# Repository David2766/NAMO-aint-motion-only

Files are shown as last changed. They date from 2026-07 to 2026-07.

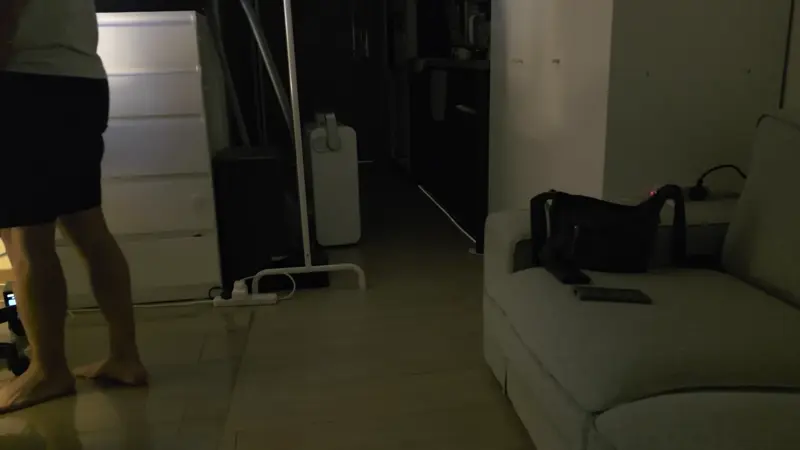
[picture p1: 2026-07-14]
docs/img/0_1.webp

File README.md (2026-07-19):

# NAMO

**NAMO Ain't Motion-Only.**<br>
*Still here, even when you're still.*

A fully local mmWave spatial presence platform with live floorplan tracking, visual zones, and Home Assistant integration.

NAMO zone-based lighting automation demo
*As I move between detection zones, NAMO automatically switches the corresponding room lights using fully local presence detection.*

## English

NAMO is a fully local mmWave spatial presence platform with live floorplan tracking, visual zones, and Home Assistant integration.

It provides open-source ESPHome firmware for an XIAO ESP32S3 and LD2450-based presence sensor, external components, and a web dashboard embedded directly into the ESP32 firmware.

### What's Included

- ESPHome firmware entry file: `namo.yaml`
- Shared ESPHome package: `packages/namo/`
- ESPHome external component: `components/radar_api_server/`
- Embedded web dashboard source: `dashboard/`
- Release binaries: `release-assets/`

### Demo

A browser-only demo is available so you can try the embedded dashboard UI without an ESP32 device.

- Dashboard demo: https://david2766.github.io/NAMO-aint-motion-only/
- Initial Wi-Fi setup demo: https://david2766.github.io/NAMO-aint-motion-only/?setup=1

The demo uses mock data. It does not change real device settings, save Wi-Fi credentials, or perform firmware updates.

To run the dashboard locally:

```powershell
cd dashboard
npm ci
npm run dev:web
```

Then open one of the following URLs:

```text
http://localhost:5173/dashboard/?demo=1
http://localhost:5173/dashboard/?setup=1
```

### Project Status

<!-- release-firmware-version -->
NAMO v0.5.5 is currently a public beta.

PIR and confirmed LD2450 tracking can start a presence session, while the LD2450 also provides target position, room, zone, and exit evidence. New hardware can attach an optional LD2410C to maintain an already established session when the LD2450 loses a motionless person. The LD2410C cannot start presence by itself or create motion and spatial tracking results. NAMO is designed to retain presence more reliably than motion-only sensors, but perfectly motionless presence detection is not guaranteed in every room or installation. Detection performance depends on placement, range, orientation, and the surrounding environment.

LD2410C assistance arms only after its detection overlaps PIR or confirmed LD2450 presence for 2 seconds. Confirmed exit evidence or filter blocking vetoes the assistance. If stable presence ends without either veto, an armed LD2410C may reassert the same session for up to 30 seconds. Its detection distance is stabilized with a three-sample median for held-target display. Missing or unavailable LD2410C hardware is ignored, leaving the existing PIR and LD2450 behavior unchanged.

### Quick Start

Most users should use the prebuilt release binaries instead of building the firmware manually.

1. Download the firmware files from `release-assets/v<version>/` or from GitHub Releases.
2. For the first installation, follow the USB flashing instructions below and install the `factory` image.
3. For updating an already installed device, use the `ota` image.
4. After boot, connect to the device setup AP.
5. Open `http://192.168.4.1/setup` in a browser.
6. Select your Wi-Fi network and enter the password.
7. Copy the ESPHome API key shown on the setup screen.
8. After setup is complete, choose your integration mode from the dashboard.

The setup AP password is:

```text
psensor7777
```

The setup AP is a temporary network used only for initial provisioning. After Wi-Fi setup is complete, the device runs on your home Wi-Fi network.

### First USB Flash

1. Download `namo-v<version>-factory.bin` from GitHub Releases.
2. Connect the XIAO ESP32S3 to your computer with a data-capable USB cable.
3. Open [ESPHome Web](https://web.esphome.io/) in Chrome or Edge.
4. Click **Connect** and select the XIAO serial port.
5. Click **Install** and select the downloaded `factory` binary.
6. Wait for installation and reboot to complete.
7. Connect to the device setup AP and continue at `http://192.168.4.1/setup`.

Use the `ota` binary only for updates from the installed device's web dashboard. Do not use the `factory` binary for OTA updates.

### Hardware

NAMO requires a Seeed Studio XIAO ESP32S3 with 8MB Flash / 8MB PSRAM and an LD2450-series radar. The LD2410C presence-assist radar, PIR, light, and environmental sensors are optional.

See the [hardware guide](hardware/README.md) for the complete parts list, pinout, wiring notes, PCB manufacturing files, enclosure models, and DIY build instructions.

The current dual-radar Gerber files and schematic are published. The matching dual-radar enclosure is still being refined; the enclosure files currently available in the repository are for the earlier single-radar build.

### Device Name

The firmware uses ESPHome's `name_add_mac_suffix`.

This prevents name conflicts when flashing the same firmware to multiple devices. Devices will be registered with names similar to:

```text
presence-sensor-aabbcc
Presence Sensor AABBCC
```

The last six characters are generated from the last three bytes of the ESP32 Wi-Fi MAC address.

### Initial Setup

This firmware does not ship with a preconfigured Wi-Fi SSID or password.

Initial setup is done through the embedded `/setup` page. The user selects a Wi-Fi network and enters the password, then the device connects to that network and becomes available through the web dashboard.

The ESPHome API encryption key is generated automatically during the initial Wi-Fi setup flow. Copy the key shown on the screen and use it when adding the device to Home Assistant.

If you only use the SmartThings Edge Driver, you still need to complete the initial setup handoff once. The dashboard will ask you to choose the intended integration mode.

### Build

To build the firmware manually, validate and compile the ESPHome configuration from the repository root:

```powershell
esphome config namo.yaml
esphome compile namo.yaml
```

To generate the embedded web dashboard asset first:

```powershell
cd dashboard
npm install
npm run build:dashboard
```

The dashboard build generates:

```text
components/radar_api_server/dashboard_assets.h
```

To run dashboard tests from a downloaded source archive:

```powershell
cd dashboard
npm test
```

The normal `npm test` command runs setup-page i18n checks, replay parser tests,
and dashboard tests. Native PresenceTracker tests are separate because they
require `cl`, `g++`, or `clang++`; run `npm run test:native` explicitly. That
command fails with a clear message when no supported host compiler is available.

### Release Files

Release binaries are included under:

```text
release-assets/v<firmware-version>/
```

The files are split by purpose:

- `factory`: use this for the first USB flash
- `ota`: use this for updating an already installed device from the web dashboard

Use `checksums.txt` to verify downloaded file integrity.

### Web Dashboard

After flashing the device, open the dashboard in a browser:

```text
http://<device-ip>/dashboard
```

Main dashboard features:

- Real-time presence and motion status
- Radar target map
- Floorplan setup and editing
- Detection zones and false-positive correction zones
- Backup and restore
- Firmware update UI
- System information
- Home Assistant / SmartThings Edge mode selection
- Statistics and heatmap views

### Core Workflow

#### 1. Dashboard

View real-time presence, motion, and target status together with room-level presence and system information in one place.

When an LD2410C is available, the dashboard also shows whether the auxiliary presence sensor currently detects a target.

NAMO dashboard

#### 2. Radar Map

Track the position and movement of up to three LD2450 targets in real time using the radar's own coordinate system.

From the Zone Settings radar map, an available LD2410C can be tuned by distance band. Per-gate engineering telemetry is enabled only while the tuning panel is open and is disabled again when the panel closes.

NAMO radar map

#### 3. Floorplan Onboarding

Upload a floorplan, set its physical size and scale, analyze wall and room candidates, and place the radar through a guided workflow.

NAMO floorplan onboarding

#### 4. Room Editing

Refine automatically detected rooms with vertex editing, split and merge operations, or manually created room boundaries.

NAMO room editing

#### 5. Radar Position & Zone Editing

Match the radar's position and rotation to the floorplan, then edit detection, exclusion, correction, and exit areas while viewing the actual room layout.

NAMO radar position and zone editing

#### 6. Furniture Layout

Select a room, add furniture, and move, rotate, or resize each object so the floorplan reflects the real space more closely.

NAMO furniture layout

### Security Notes

Each device should use its own ESPHome API encryption key.

During initial setup, this firmware detects the default demo key, generates a new API key, and shows it to the user for copying.

Do not publish firmware images built with your personal settings. Before sharing a ROM file, make sure it does not contain your real Wi-Fi credentials or private API key.

The embedded dashboard is designed for local-network use. Avoid exposing the device directly to the public internet.

### Documentation

- [Documentation index](docs/README.md)
- [HTTP API contract](docs/api-contract.md)
- [Multi-sensor API design](docs/multi-sensor-contract.md)
- [Exit evidence](docs/presence-exit-zone.md)
- [Presence tracker](docs/presence-tracker.md)
- [Future tracker work](docs/presence-tracker-future.md)
- [Replay and validation plan](docs/presence-replay.md)
- [Presence simulation plan](docs/presence-simulation.md)

### Related Repositories

This project works together with the following repositories:

- NAMO firmware / embedded web dashboard: https://github.com/David2766/NAMO-aint-motion-only
- Home Assistant custom card: https://github.com/David2766/radar-zone-card-for-LD2450
- SmartThings Edge Driver: https://github.com/David2766/presence-sensor-smartthings-edge

### License

Copyright (c) 2026 David2766 and contributors.

The software and firmware are licensed under AGPL-3.0-or-later.

The hardware design and manufacturing files under [`hardware/`](hardware/) are licensed separately under [CC BY-NC-SA 4.0](hardware/LICENSE).

Third-party components retain their respective licenses. See [Third-Party Notices](THIRD_PARTY_NOTICES.md) and [Third-Party License Texts](THIRD_PARTY_LICENSES.txt).

### Notes

This project was planned and tested by the author, with OpenAI Codex used for code generation and refactoring throughout development.

---

## 한국어

NAMO는 실시간 평면도 추적, 시각적 감지 구역과 Home Assistant 연동을 제공하는 완전 로컬 방식의 mmWave 공간 재실 플랫폼입니다.

이 저장소에는 XIAO ESP32S3와 LD2450 기반 재실 센서용 오픈소스 ESPHome 펌웨어, 외부 컴포넌트, 그리고 ESP32 펌웨어에 직접 내장되는 웹 대시보드 소스가 포함되어 있습니다.

### 포함된 것

- ESPHome 펌웨어 진입 파일: `namo.yaml`
- ESPHome 공통 패키지: `packages/namo/`
- ESPHome 외부 컴포넌트: `components/radar_api_server/`
- 내장 웹 대시보드 소스: `dashboard/`
- 릴리즈 바이너리: `release-assets/`

### 데모 웹 페이지

실제 ESP32 기기 없이 내장 웹 대시보드 화면을 확인할 수 있는 데모 페이지를 제공합니다.

- 데모 주소: https://david2766.github.io/NAMO-aint-motion-only/
- 초기 Wi-Fi 설정 화면 데모: https://david2766.github.io/NAMO-aint-motion-only/?setup=1

데모에서는 데모 데이터를 사용하며 실제 기기 설정, Wi-Fi 저장, 펌웨어 업데이트는 수행하지 않습니다.

로컬에서 확인하려면 아래 명령을 사용합니다.

```powershell
cd dashboard
npm ci
npm run dev:web
```

그 다음 브라우저에서 아래 주소로 접속합니다.

```text
http://localhost:5173/dashboard/?demo=1
http://localhost:5173/dashboard/?setup=1
```

### 프로젝트 상태

<!-- release-firmware-version -->
NAMO v0.5.5는 현재 공개 베타 단계입니다.

PIR과 확정된 LD2450 트랙은 재실 세션을 시작할 수 있으며, LD2450은 타깃 위치, 방, 구역 및 퇴실 근거도 제공합니다. 신규 하드웨어에서는 선택 사항인 LD2410C가 LD2450이 움직이지 않는 사람을 놓쳤을 때 이미 시작된 재실을 유지할 수 있습니다. LD2410C 단독으로 재실을 새로 켜거나 움직임 및 공간 추적 결과를 만들지는 않습니다. NAMO는 움직임만 감지하는 센서보다 재실 상태를 안정적으로 유지하도록 설계되었지만, 모든 방과 설치 환경에서 완전히 움직이지 않는 사람의 감지를 보장하지는 않습니다. 감지 성능은 센서 배치, 거리, 방향 및 주변 환경의 영향을 받습니다.

LD2410C 보조는 PIR 또는 확정된 LD2450 재실과 2초 동안 함께 감지된 뒤에만 준비됩니다. 확인된 퇴실 근거나 필터 차단이 있으면 보조를 사용하지 않습니다. 두 차단 근거 없이 안정화 재실이 종료되면 준비된 LD2410C가 최대 30초 동안 같은 재실 세션을 다시 이어갈 수 있습니다. 보존 타깃 표시에 사용하는 감지 거리는 3개 표본의 중앙값으로 안정화합니다. LD2410C가 없거나 통신할 수 없으면 조용히 무시하고 기존 PIR 및 LD2450 동작을 그대로 유지합니다.

### 빠른 시작

일반 사용자는 직접 빌드하지 않고 릴리즈 바이너리를 사용하는 것을 권장합니다.

1. `release-assets/v<version>/` 또는 GitHub Releases에서 펌웨어 파일을 받습니다.
2. 처음 설치할 때는 아래 USB 플래싱 절차에 따라 `factory` 이미지를 설치합니다.
3. 이미 설치된 기기를 업데이트할 때는 `ota` 이미지를 사용합니다.
4. 부팅 후 기기의 설정 AP에 접속합니다.
5. 브라우저에서 `http://192.168.4.1/setup`으로 접속합니다.
6. 사용할 Wi-Fi를 선택하고 비밀번호를 입력합니다.
7. 화면에 표시되는 ESPHome API 키를 복사합니다.
8. 설정 완료 후 대시보드에서 사용 환경을 선택합니다.

설정 AP 비밀번호는 아래와 같습니다.

```text
psensor7777
```

설정 AP는 초기 설정을 위한 임시 네트워크입니다. Wi-Fi 설정이 완료되면 기기는 집 Wi-Fi로 동작합니다.

### 최초 USB 플래싱

1. GitHub Releases에서 `namo-v<version>-factory.bin`을 받습니다.
2. 데이터 전송이 가능한 USB 케이블로 XIAO ESP32S3를 컴퓨터에 연결합니다.
3. Chrome 또는 Edge에서 [ESPHome Web](https://web.esphome.io/)을 엽니다.
4. **Connect**를 누르고 XIAO의 시리얼 포트를 선택합니다.
5. **Install**을 누르고 다운로드한 `factory` 바이너리를 선택합니다.
6. 설치와 재부팅이 끝날 때까지 기다립니다.
7. 기기의 설정 AP에 연결한 뒤 `http://192.168.4.1/setup`에서 설정을 계속합니다.

`ota` 바이너리는 설치된 기기의 웹 대시보드에서 업데이트할 때만 사용합니다. OTA 업데이트에 `factory` 바이너리를 사용하지 마세요.

### 하드웨어

NAMO에는 8MB Flash / 8MB PSRAM 사양의 Seeed Studio XIAO ESP32S3와 LD2450 계열 레이더가 필요합니다. LD2410C 재실 보조 레이더, PIR, 조도 및 온습도 센서는 선택 사항입니다.

전체 부품 목록, 핀맵, 배선 주의사항, PCB 제작 파일, 케이스 모델 및 자작 안내는 [하드웨어 가이드](hardware/README.ko.md)를 참고하세요.

현재 듀얼 레이더 Gerber 파일과 회로도는 공개되어 있습니다. 듀얼 레이더용 케이스는 계속 다듬는 중이며, 저장소에 현재 공개된 케이스 파일은 구형 단일 레이더 구성용입니다.

### 기기 이름

ESPHome의 `name_add_mac_suffix`를 사용합니다.

따라서 같은 펌웨어를 여러 기기에 넣어도 이름 충돌이 나지 않습니다. 기기는 대략 아래와 같은 이름으로 등록됩니다.

```text
presence-sensor-aabbcc
Presence Sensor AABBCC
```

뒤의 6자리는 ESP32 Wi-Fi MAC 주소의 마지막 3바이트를 기준으로 생성됩니다.

### 초기 설정

이 펌웨어는 Wi-Fi SSID와 비밀번호를 펌웨어에 미리 넣지 않습니다.

초기 설정은 기기 안에 내장된 `/setup` 화면에서 진행합니다. 사용자가 Wi-Fi를 선택하고 비밀번호를 입력하면 기기가 해당 네트워크에 연결되고, 이후 웹 대시보드에서 사용할 수 있습니다.

ESPHome API 보안 키는 초기 Wi-Fi 설정 과정에서 자동으로 생성됩니다. 화면에 표시되는 키를 복사해 두었다가 Home Assistant에 기기를 추가할 때 사용합니다.

SmartThings Edge Driver만 사용하는 경우에도 초기 설정 마무리 과정은 한 번 진행해야 합니다. 대시보드에서 사용 환경을 선택하면 됩니다.

### 빌드

직접 빌드하려면 저장소 루트에서 ESPHome으로 설정을 확인하고 빌드합니다.

```powershell
esphome config namo.yaml
esphome compile namo.yaml
```

내장 웹 대시보드 asset을 먼저 생성하려면 아래 명령을 실행합니다.

```powershell
cd dashboard
npm install
npm run build:dashboard
```

대시보드 빌드는 아래 파일을 생성합니다.

```text
components/radar_api_server/dashboard_assets.h
```

다운로드한 소스 압축 파일에서 대시보드 테스트를 실행하려면 다음 명령을 사용합니다.

```powershell
cd dashboard
npm test
```

일반 `npm test`는 setup page i18n 검사, 리플레이 파서 테스트와 대시보드 테스트를
실행합니다. 네이티브 PresenceTracker 테스트는 `cl`, `g++`, `clang++` 중 하나가
필요하므로 `npm run test:native`로 별도 실행합니다. 지원하는 호스트 컴파일러가
없으면 이 명령은 원인을 명확히 표시하고 실패합니다.

### 릴리즈 파일

릴리즈용 바이너리는 아래 폴더에 포함됩니다.

```text
release-assets/v<firmware-version>/
```

파일 이름은 용도에 따라 나뉩니다.

- `factory`: 처음 USB로 플래시할 때 사용
- `ota`: 이미 설치된 기기를 웹 대시보드에서 업데이트할 때 사용

`checksums.txt`로 다운로드한 파일의 무결성을 확인할 수 있습니다.

### 웹 대시보드

기기 플래싱 후 브라우저에서 아래 주소로 접속합니다.

```text
http://<device-ip>/dashboard
```

웹 대시보드에서 제공하는 주요 기능은 다음과 같습니다.

- 실시간 재실 / 움직임 상태 확인
- 레이더 타깃 맵
- 평면도 설정 및 편집
- 감지 구역 / 오탐 보정 구역 설정
- 백업 및 복원
- 펌웨어 업데이트 UI
- 시스템 정보 확인
- Home Assistant / SmartThings Edge 사용 모드 선택
- 통계 및 히트맵 보기

### 핵심 사용 흐름

#### 1. 대시보드

실시간 재실·움직임·타깃 상태와 방별 재실 상태 및 시스템 정보를 한 화면에서 확인합니다.

LD2410C가 연결되어 있으면 보조 재실 센서가 현재 타깃을 감지하는지도 함께 표시합니다.

NAMO 대시보드

#### 2. 레이더맵

최대 3개 LD2450 타깃의 위치와 움직임을 레이더 좌표계에서 실시간으로 확인합니다.

구역 설정의 레이더맵에서는 연결된 LD2410C의 거리 띠별 민감도를 조절할 수 있습니다. 게이트별 engineering 계측은 튜닝 패널을 연 동안에만 활성화되고 패널을 닫으면 다시 비활성화됩니다.

NAMO 레이더맵

#### 3. 평면도 온보딩

평면도를 업로드하고 실제 크기와 축척을 설정한 뒤, 벽과 방 후보 분석 및 레이더 초기 배치를 단계별로 진행합니다.

NAMO 평면도 온보딩

#### 4. 방 편집

자동 인식된 방을 꼭짓점 편집, 분할, 병합으로 다듬거나 방 경계를 직접 생성할 수 있습니다.

NAMO 방 편집

#### 5. 레이더 위치 및 구역 편집

평면도 위에서 레이더 위치와 회전을 맞추고, 실제 공간을 보면서 감지 구역, 제외·오탐 보정 구역 및 퇴실 지점을 편집합니다.

NAMO 레이더 위치 및 구역 편집

#### 6. 가구 배치

방을 선택해 가구를 추가하고 이동, 회전, 크기 조절을 통해 평면도를 실제 공간과 비슷하게 구성합니다.

NAMO 가구 배치

### 보안 주의

ESPHome API 보안 키는 기기마다 고유하게 사용하는 것을 권장합니다.

이 펌웨어는 초기 설정 과정에서 기본 데모 키를 감지하면 새 API 키를 자동 생성하고, 사용자가 복사할 수 있도록 안내합니다.

개인 설정을 넣어 직접 빌드한 펌웨어 이미지를 공개하지 마세요. ROM 파일을 공유하고 싶다면 실제 사용 중인 Wi-Fi 정보나 개인 API 키가 포함되지 않았는지 확인해야 합니다.

내장 대시보드는 로컬 네트워크 사용을 전제로 합니다. 기기를 인터넷에 직접 노출하지 않는 것을 권장합니다.

### 관련 문서

- [문서 인덱스](docs/README.ko.md)
- [HTTP API 계약](docs/api-contract.ko.md)
- [다중 센서 API 설계](docs/multi-sensor-contract.ko.md)
- [퇴실 근거](docs/presence-exit-zone.ko.md)
- [재실 트래커](docs/presence-tracker.ko.md)
- [향후 트래커 작업](docs/presence-tracker-future.ko.md)
- [리플레이 및 검증 계획](docs/presence-replay.ko.md)
- [재실 시뮬레이션 계획](docs/presence-simulation.ko.md)

### 관련 저장소

이 프로젝트는 아래 저장소들과 함께 동작합니다.

- NAMO 펌웨어 / 내장 웹 대시보드: https://github.com/David2766/NAMO-aint-motion-only
- Home Assistant 커스텀 카드: https://github.com/David2766/radar-zone-card-for-LD2450
- SmartThings Edge Driver: https://github.com/David2766/presence-sensor-smartthings-edge

### 라이선스

Copyright (c) 2026 David2766 and contributors.

소프트웨어와 펌웨어는 AGPL-3.0-or-later 라이선스로 배포됩니다.

[`hardware/`](hardware/) 아래의 하드웨어 설계 및 제작 파일은 별도의 [CC BY-NC-SA 4.0](hardware/LICENSE) 라이선스로 배포됩니다.

제3자 구성요소에는 각 구성요소의 라이선스가 적용됩니다. 자세한 내용은 [제3자 고지](THIRD_PARTY_NOTICES.md)와 [제3자 라이선스 전문](THIRD_PARTY_LICENSES.txt)을 참고하세요.

### 기타

이 프로젝트는 제작자가 직접 기획하고 테스트하면서, 코드 작성과 리팩토링 과정에 OpenAI Codex를 활용해 개발했습니다.

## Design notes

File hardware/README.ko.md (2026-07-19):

# NAMO 하드웨어

[English](README.md)

이 폴더에는 NAMO의 기준 하드웨어 정보와 제작 파일이 들어 있습니다.

> [!IMPORTANT]
> 현재 듀얼 레이더 PCB 제작 파일과 회로도는 [`pcb/dual_sensor/`](pcb/dual_sensor/)에 공개되어 있습니다. 케이스 파일과 완성품 사진은 아직 구형 단일 레이더 세대의 자료입니다. 듀얼 레이더용 케이스는 계속 다듬는 중이며 아직 공개하지 않았으므로, 현재 듀얼 레이더 보드에 구형 케이스를 그대로 출력하지 마세요.

## 제작 사진

| 1. 구형 단일 레이더 PCB | 1-1. 현재 듀얼 레이더 PCB |
| --- | --- |
| NAMO 구형 단일 레이더 PCB | NAMO 현재 듀얼 레이더 PCB |
| 2. BH1750FVI 조도 센서 | 3. FPC-SHT40 온습도 센서 |
| NAMO BH1750FVI 조도 센서 | NAMO FPC-SHT40 온습도 센서 |
| 4. LD2450 레이더 | 4-1. LD2410C 정적 재실 레이더 |
| NAMO LD2450 레이더 | NAMO LD2410C 정적 재실 레이더 |
| 5. 조립 완료 후 후면을 닫기 전 상태 | 6. 최종 조립 상태 |
| NAMO 조립 완료 후 후면을 닫기 전 상태 | NAMO 최종 조립 상태 |

1번은 구형 단일 레이더 PCB, 1-1번은 현재 듀얼 레이더 PCB입니다. 2-6번은 구형 구성의 부품과 조립 상태를 보여주며, 4-1번은 현재 설계에서 선택적으로 사용하는 LD2410C입니다. 듀얼 레이더용 케이스와 최종 조립 사진은 케이스 설계가 확정된 뒤 추가할 예정입니다.

## 지원 하드웨어

| 하드웨어 | 필수 여부 | 설명 |
| --- | ---: | --- |
| Seeed Studio XIAO ESP32S3, 8MB Flash / 8MB PSRAM | 필수 | 현재 파티션 및 메모리 구성에 필요 |
| LD2450 계열 mmWave 레이더 | 필수 | 재실 시작 및 공간 추적 센서 |
| LD2410C 정적 재실 레이더 | 선택 | 사용 가능할 때 이미 시작된 재실 세션을 유지 |
| Panasonic EKMC1603111 PIR 센서 | 선택 | GPIO1 사용; 생략할 경우 입력이 전기적으로 안정되어야 함 |
| BH1750 조도 센서 | 선택 | I2C 버스 공유 |
| SHT4x 온습도 센서 | 선택 | I2C 버스 공유 |

이 펌웨어는 8MB Flash / 8MB PSRAM 모델과 커스텀 파티션 구성을 기준으로 합니다. Flash 용량이 작거나 PSRAM이 없는 ESP32-S3 보드, 또는 ESP32-C6 같은 다른 칩 계열에서는 그대로 동작하지 않을 수 있습니다.

## 핀 연결

기준 펌웨어와 PCB는 Seeed Studio XIAO ESP32S3의 아래 핀 배열을 사용합니다.

| 기능 | XIAO 표기 | ESP32 GPIO | 연결 대상 |
| --- | --- | --- | --- |
| PIR 입력 | D0 | GPIO1 | PIR 센서 OUT |
| I2C SDA | D4 | GPIO5 | BH1750 SDA, SHT4x SDA |
| I2C SCL | D5 | GPIO6 | BH1750 SCL, SHT4x SCL |
| LD2410C UART TX | D1 | GPIO2 | LD2410C RX |
| LD2410C UART RX | D2 | GPIO3 | LD2410C TX |
| LD2450 UART TX | D6 | GPIO43 | LD2450 RX |
| LD2450 UART RX | D7 | GPIO44 | LD2450 TX |
| 상태 LED | 내장 LED | GPIO21 | XIAO 내장 사용자 LED |
| 초기화 버튼 | BOOT | GPIO0 | XIAO BOOT 버튼 |

## 배선 주의사항

LD2450과 LD2410C의 TX/RX는 각각 XIAO UART와 교차 연결합니다. XIAO의 TX는 레이더 RX로, XIAO의 RX는 레이더 TX로 연결합니다.

GPIO3은 ESP32-S3의 strapping pin입니다. 기준 보드는 이 핀을 LD2410C TX에 연결하므로, 부팅 strap level을 강제로 바꿀 수 있는 외부 pull-up 또는 pull-down 저항을 추가하지 마세요.

BH1750과 SHT4x는 같은 I2C 버스를 공유합니다. 각 모듈의 동작 전압을 확인한 뒤 전원을 연결하고, 모든 모듈의 GND를 XIAO의 GND와 공통으로 묶어야 합니다.

LD2450은 재실, 타깃 추적 및 구역 감지에 반드시 필요합니다. LD2450이 없어도 펌웨어가 부팅될 수는 있지만 해당 기능은 정상적으로 동작하지 않습니다.

LD2410C는 런타임 선택 사항입니다. 장착된 경우 PIR 또는 확정된 LD2450 트랙이 이미 시작한 재실 세션을 유지할 수 있습니다. LD2410C 단독으로 재실을 새로 켜지 않으며 움직임, 타깃 좌표와 개수, 방 상태 또는 구역 재실을 만들지 않습니다. raw 재실, 이동/정지 거리와 energy는 진단에 유지되며, replay에는 안정화된 기준 감지 거리와 보조 상태도 기록됩니다.

보조 기능은 LD2410C 감지가 PIR 또는 확정된 LD2450 재실과 2초 동안 겹친 뒤에만 준비됩니다. 확인된 퇴실 근거와 필터 차단은 보조를 막습니다. 두 차단 근거가 없으면 준비된 LD2410C가 최근 종료된 동일 재실 세션에 대해 30초 재진입 시간을 가집니다. 기준 감지 거리는 3개 표본의 중앙값을 사용합니다. 하드웨어가 없으면 조용히 무시하며, 대시보드 튜닝 세션은 패널을 연 동안에만 게이트별 engineering 계측을 활성화합니다.

BH1750, SHT4x 및 PIR 센서는 생략할 수 있습니다. 이 경우 해당 센서 값이 표시되지 않고 로그에 경고가 남을 수 있습니다. PIR 센서를 생략한다면 GPIO1 입력이 떠서 오탐이 발생하지 않도록 회로에서 안정적으로 처리하거나 YAML의 PIR 관련 설정을 제거하세요.

## PCB 제작 파일

현재 듀얼 레이더 설계에는 위 핀맵에 설명한 선택 사항인 LD2410C UART 연결이 추가되어 있습니다. 이전 단일 레이더 보드는 레거시 참고 자료로 함께 유지합니다.

- 현재 듀얼 레이더 보드: [Gerber 압축 파일](pcb/dual_sensor/Gerber.zip) · [회로도](pcb/dual_sensor/schematic.png)
- 구형 단일 레이더 보드: [Gerber 압축 파일](pcb/single_sensor/Gerber.zip) · [회로도](pcb/single_sensor/schematic.png)

주문하기 전에 선택한 제작 압축 파일, 회로도, 전원 전압, 커넥터 방향 및 보드 요구사항을 직접 확인하세요. 현재 LD2450 + LD2410C 기준 하드웨어를 제작할 때는 듀얼 레이더 파일을 사용해야 합니다.

## 케이스 모델

아래 케이스 파일은 구형 단일 레이더 하드웨어 세대에 맞춘 모델입니다. 듀얼 레이더 배치용 신형 케이스는 현재 계속 다듬는 중이며 아직 공개하지 않았습니다.

- [상단 케이스](enclosure/top.3mf)
- [하단 케이스](enclosure/bottom.3mf)

3MF 파일을 슬라이서에서 열고 크기, 출력 방향, 서포트 및 재료 설정을 확인한 뒤 출력하세요. 프린터 보정 상태와 재료 수축에 따라 최종 결합 상태가 달라질 수 있습니다.

구형 케이스 모델은 수정 없이 현재 듀얼 레이더 PCB와 센서 배치에 맞지 않을 수 있습니다.

## 자작 구성 참고

동일한 XIAO ESP32S3 보드와 위 핀맵을 사용하면 호환 기기를 직접 제작할 수 있습니다. 전원을 넣기 전에 각 모듈의 전원 전압과 핀 방향을 반드시 확인하세요.

PCB와 케이스 파일은 위에 명시된 펌웨어 핀맵을 기준으로 사용해야 합니다. 회로나 커넥터 배치가 바뀌면 펌웨어 설정과 이 문서를 함께 갱신해야 합니다.

## 라이선스

Copyright (c) 2026 David2766.

이 디렉터리의 하드웨어 설계 및 제작 파일은 [Creative Commons 저작자표시-비영리-동일조건변경허락 4.0 국제 라이선스](LICENSE)(`CC BY-NC-SA 4.0`)로 배포됩니다. 상업적 사용에는 프로젝트 제작자의 별도 허가가 필요합니다.

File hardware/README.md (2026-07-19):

# NAMO Hardware

[한국어](README.ko.md)

This directory contains the reference hardware information and manufacturing files for NAMO.

> [!IMPORTANT]
> The current dual-radar PCB manufacturing package and schematic are now published under [`pcb/dual_sensor/`](pcb/dual_sensor/). The enclosure files and assembled-device photos still belong to the earlier single-radar generation. A dual-radar enclosure is being refined and is not yet published; do not print the legacy enclosure for the current dual-radar board.

## Build Gallery

| 1. Legacy single-radar PCB | 1-1. Current dual-radar PCB |
| --- | --- |
| NAMO legacy single-radar PCB | NAMO current dual-radar PCB |
| 2. BH1750FVI light sensor | 3. FPC-SHT40 temperature and humidity sensor |
| NAMO BH1750FVI light sensor | NAMO FPC-SHT40 sensor |
| 4. LD2450 radar | 4-1. LD2410C static-presence radar |
| NAMO LD2450 radar | NAMO LD2410C static-presence radar |
| 5. Rear view before closing the enclosure | 6. Final assembly |
| NAMO assembled hardware before closing the rear enclosure | NAMO final assembly |

Photo 1 shows the earlier single-radar PCB, while photo 1-1 shows the current dual-radar PCB. Photos 2-6 document components and assembly from the earlier build, and photo 4-1 shows the optional LD2410C used by the current design. Updated dual-radar enclosure and final-assembly photos will be added after the enclosure is finalized.

## Supported Hardware

| Hardware | Required | Notes |
| --- | ---: | --- |
| Seeed Studio XIAO ESP32S3, 8MB Flash / 8MB PSRAM | Yes | Required by the current partition and memory configuration |
| LD2450-series mmWave radar | Yes | Presence acquisition and spatial tracking sensor |
| LD2410C static-presence radar | Optional | Maintains an already established presence session when available |
| Panasonic EKMC1603111 PIR sensor | Optional | Uses GPIO1; an omitted input must remain electrically stable |
| BH1750 light sensor | Optional | Shares the I2C bus |
| SHT4x temperature and humidity sensor | Optional | Shares the I2C bus |

The firmware assumes an 8MB Flash / 8MB PSRAM model and a custom partition layout. ESP32-S3 boards with smaller flash, no PSRAM, or other ESP32 chip families such as ESP32-C6 may not work as-is.

## Pinout

The reference firmware and PCB use the following Seeed Studio XIAO ESP32S3 pin layout.

| Function | XIAO Label | ESP32 GPIO | Connected To |
| --- | --- | --- | --- |
| PIR input | D0 | GPIO1 | PIR sensor OUT |
| I2C SDA | D4 | GPIO5 | BH1750 SDA, SHT4x SDA |
| I2C SCL | D5 | GPIO6 | BH1750 SCL, SHT4x SCL |
| LD2410C UART TX | D1 | GPIO2 | LD2410C RX |
| LD2410C UART RX | D2 | GPIO3 | LD2410C TX |
| LD2450 UART TX | D6 | GPIO43 | LD2450 RX |
| LD2450 UART RX | D7 | GPIO44 | LD2450 TX |
| Status LED | Built-in LED | GPIO21 | XIAO built-in user LED |
| Reset button | BOOT | GPIO0 | XIAO BOOT button |

## Wiring Notes

The LD2450 and LD2410C TX/RX pins must be crossed with the corresponding XIAO UART pins: XIAO TX goes to radar RX, and XIAO RX goes to radar TX.

GPIO3 is an ESP32-S3 strapping pin. The reference board routes it to LD2410C TX; avoid adding external pull-up or pull-down resistors that can force an invalid boot strap level.

BH1750 and SHT4x share the same I2C bus. Check the operating voltage of each module before wiring power, and connect all module grounds to the XIAO GND.

The LD2450 is required for presence, target tracking, and zone detection. The firmware may boot without it, but those features will not work correctly.

LD2410C support is optional at runtime. When present, it may maintain a presence session that PIR or confirmed LD2450 tracking already started. It cannot start presence by itself and does not create motion, target coordinates, target counts, room state, or zone presence. Raw presence, moving/still distances and energy remain available for diagnostics; replay also records the stabilized canonical detection distance and assist state.

Assistance arms only after LD2410C detection overlaps PIR or confirmed LD2450 presence for 2 seconds. Confirmed exit evidence and filter blocking veto the assistance. Without either veto, an armed LD2410C has a 30-second reentry window for the same recently ended session. Its canonical detection distance uses a three-sample median. Missing hardware is ignored, and the dashboard tuning session enables per-gate engineering telemetry only while the tuning panel is open.

The BH1750, SHT4x, and PIR sensors may be omitted. Their values will not be available and warnings may appear in the logs. If the PIR sensor is omitted, keep GPIO1 electrically stable or remove the PIR-related YAML configuration to prevent false triggers.

## PCB Manufacturing Files

The current dual-radar design adds the optional LD2410C UART connection documented in the pinout above. The previous single-radar board remains available as a legacy reference.

- Current dual-radar board: [Gerber archive](pcb/dual_sensor/Gerber.zip) · [Schematic](pcb/dual_sensor/schematic.png)
- Legacy single-radar board: [Gerber archive](pcb/single_sensor/Gerber.zip) · [Schematic](pcb/single_sensor/schematic.png)

Review the selected manufacturing archive, schematic, supply voltages, connector orientation, and board requirements before ordering. Use the dual-radar package when building the current LD2450 + LD2410C reference hardware.

## Enclosure Models

The following enclosure files fit the earlier single-radar hardware generation. The updated enclosure for the dual-radar layout is still being refined and is not yet published.

- [Top enclosure](enclosure/top.3mf)
- [Bottom enclosure](enclosure/bottom.3mf)

Open the 3MF files in your slicer and verify scale, orientation, supports, and material settings before printing. Printer calibration and material shrinkage can affect the final fit.

These legacy models are not expected to fit the current dual-radar PCB and sensor arrangement without modification.

## DIY Build Notes

You can build a compatible device with the same XIAO ESP32S3 board by following the documented pinout. Confirm every module's supply voltage and pin direction before applying power.

The PCB and enclosure files must be used with the firmware pinout documented above. If the circuit or connector layout changes, update both the firmware configuration and this guide together.

## License

Copyright (c) 2026 David2766.

The hardware design and manufacturing files in this directory are licensed under the [Creative Commons Attribution-NonCommercial-ShareAlike 4.0 International license](LICENSE) (`CC BY-NC-SA 4.0`). Commercial use requires separate permission from the project author.

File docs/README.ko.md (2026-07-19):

# 문서 인덱스

어떤 프로젝트 문서를 읽거나 수정해야 하는지 판단할 때 여기서 시작한다.

## 현재 계약

- [api-contract.md](api-contract.md): 안정화된 HTTP API 응답 구조, 상태 코드 규칙, 오류 코드 registry, 프론트엔드/펌웨어 호환성 규칙.
- [api-contract.ko.md](api-contract.ko.md): API 계약의 한국어 버전.

## 향후 API 설계

- [multi-sensor-contract.md](multi-sensor-contract.md): 향후 다중 센서 및 coordinator API 메모.
- [multi-sensor-contract.ko.md](multi-sensor-contract.ko.md): 다중 센서 메모의 한국어 버전.

## 재실 추적

- [presence-exit-zone.md](presence-exit-zone.md): production 트래커가 사용하는 현재 퇴실 지점 및 방 경계 근거.
- [presence-exit-zone.ko.md](presence-exit-zone.ko.md): 현재 퇴실 근거 동작의 한국어 문서.
- [presence-tracker.md](presence-tracker.md): 현재 tracker의 책임, 경계, 구현 메모.
- [presence-tracker.ko.md](presence-tracker.ko.md): 현재 tracker 메모의 한국어 버전.
- [presence-tracker-future.md](presence-tracker-future.md): 현재 획득 경계를 유지하는 향후 검증 및 튜닝 작업.
- [presence-tracker-future.ko.md](presence-tracker-future.ko.md): 향후 tracker 메모의 한국어 버전.

## 리플레이 및 시뮬레이션

- [presence-replay.md](presence-replay.md): 리플레이 로그, ground-truth 라벨링, 점수화, 도구 형태.
- [presence-replay.ko.md](presence-replay.ko.md): 리플레이 메모의 한국어 버전.
- [presence-simulation.md](presence-simulation.md): 자연스러운 움직임 및 Monte Carlo 시뮬레이션 메모.
- [presence-simulation.ko.md](presence-simulation.ko.md): 시뮬레이션 메모의 한국어 버전.

## 수정 규칙

- `api-contract.md`에는 현재 코드가 지켜야 하는 규칙만 둔다.
- 미래 설계는 별도의 future/design 문서에 둔다.
- 영어와 한국어 버전은 별도 파일로 유지한다.
- 코드 변경이 API 응답에 영향을 주면 API 계약을 먼저 또는 같은 변경에서 갱신한다.

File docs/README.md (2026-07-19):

# Documentation Index

Start here when deciding which project document to read or update.

## Current Contracts

- [api-contract.md](api-contract.md): Stable HTTP API response shape, status code rules, error code registry, and frontend/firmware compatibility rules.
- [api-contract.ko.md](api-contract.ko.md): Korean version of the API contract.

## Future API Design

- [multi-sensor-contract.md](multi-sensor-contract.md): Future multi-sensor and coordinator API notes.
- [multi-sensor-contract.ko.md](multi-sensor-contract.ko.md): Korean version of the multi-sensor notes.

## Presence Tracking

- [presence-exit-zone.md](presence-exit-zone.md): Current exit-zone and room-boundary evidence used by the production tracker.
- [presence-exit-zone.ko.md](presence-exit-zone.ko.md): Korean version of the current exit-evidence behavior.
- [presence-tracker.md](presence-tracker.md): Current tracker responsibilities, boundaries, and implementation notes.
- [presence-tracker.ko.md](presence-tracker.ko.md): Korean version of the current tracker notes.
- [presence-tracker-future.md](presence-tracker-future.md): Future validation and tuning work that preserves the current acquisition boundary.
- [presence-tracker-future.ko.md](presence-tracker-future.ko.md): Korean version of future tracker notes.

## Replay and Simulation

- [presence-replay.md](presence-replay.md): Replay log, ground-truth labeling, scoring, and tool shape.
- [presence-replay.ko.md](presence-replay.ko.md): Korean version of replay notes.
- [presence-simulation.md](presence-simulation.md): Natural motion and Monte Carlo simulation notes.
- [presence-simulation.ko.md](presence-simulation.ko.md): Korean version of simulation notes.

## Editing Rules

- Keep `api-contract.md` focused on rules that current code should obey.
- Put future designs in separate future/design documents.
- Keep English and Korean versions in separate files.
- When code changes affect an API response, update the API contract first or in the same change.

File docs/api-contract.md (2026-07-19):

# API Contract

This document defines how device APIs should report machine-readable status,
errors, and user-facing messages. The goal is to keep firmware, dashboard UI,
demo mode, and future integrations stable as the project grows.

This is not a full OpenAPI specification. It is a practical contract for this
project.

---

## 1. Scope

This contract applies first to APIs that return status or error information.
Existing APIs do not need to be rewritten all at once.

Initial targets:

- `/api/system/status`
- `/api/setup/*`
- Device config upload APIs
- Floorplan upload APIs
- Stats upload and backup/restore APIs
- Calibration-related APIs
- OTA upload and reboot confirmation flow
- Diagnostic/debug APIs

---

## 2. Core Rule

APIs should return stable codes for software and let the frontend decide the
display language.

Do this:

```json
{
  "ok": false,
  "error": {
    "code": "calibration_pir_active",
    "severity": "warning",
    "detail": {
      "pir": true
    }
  }
}
```

Avoid this for new APIs:

```json
{
  "ok": false,
  "status": "PIR motion was detected, so calibration cannot start."
}
```

---

## 3. Response Shape

### 3.1 Success Response

Successful responses must use `ok: true`.

Recommended shape:

```json
{
  "ok": true,
  "data": {},
  "status": {
    "code": "ready",
    "severity": "info",
    "detail": {}
  }
}
```

Rules:

- `ok` must be `true`.
- `data` contains domain data.
- `status` is optional when there is no useful state to report.
- If present, `status.code` must be stable and machine-readable.
- `status` must not be used for failure causes.

### 3.2 Failure Response

Failure responses must use `ok: false`.

Recommended shape:

```json
{
  "ok": false,
  "error": {
    "code": "upload_session_mismatch",
    "severity": "error",
    "detail": {
      "expected": 2,
      "received": 0
    }
  }
}
```

Rules:

- `ok` must be `false`.
- Failure cause must be placed in `error.code`.
- `error.severity` must be `warning` or `error`.
- `error.detail` should contain only small structured data.
- UI logic must not depend on `error.message`.

### 3.3 In-Progress Response

Long-running or deferred operations should return `ok: true` with a status code.

Example:

```json
{
  "ok": true,
  "status": {
    "code": "ota_reboot_waiting",
    "severity": "info",
    "detail": {
      "retryAfterMs": 2000
    }
  }
}
```

Use this for accepted operations, reboot waits, deferred actions, and polling
flows.

---

## 4. HTTP Status Code Rules

HTTP status codes describe the request/transport result. JSON `code` values
describe the device/domain state.

Recommended mapping:

| HTTP | Meaning | Use for |
|---:|---|---|
| 200 | OK | Normal synchronous success or state response |
| 202 | Accepted | Deferred action accepted, such as OTA/reboot/pending work |
| 400 | Bad Request | Missing parameter, invalid JSON, invalid target, bad chunk header |
| 401 | Unauthorized | API key or PSK is required but missing/invalid |
| 403 | Forbidden | Request is understood but blocked by current device state |
| 404 | Not Found | Unknown endpoint or resource |
| 409 | Conflict | Active session conflict, upload mismatch, operation already running |
| 413 | Payload Too Large | Upload or request body exceeds allowed size |
| 415 | Unsupported Media Type | Unsupported `Content-Type` |
| 500 | Internal Server Error | Unexpected firmware/storage/internal failure |
| 503 | Service Unavailable | Device is temporarily unavailable, rebooting, or changing network state |

Examples:

- Upload session mismatch: HTTP `409`, error code `upload_session_mismatch`.
- Boot guard blocks reset: HTTP `403`, error code `boot_guard_active`.
- Oversized floorplan image: HTTP `413`, error code `upload_payload_too_large`.
- SPIFFS write failure: HTTP `500`, error code `storage_write_failed`.

---

## 5. Status and Error Object

`code`

- Stable machine-readable identifier.
- Use lowercase `snake_case`.
- Do not use a full sentence.
- Frontend logic should depend on this, not on display text.

`severity`

- One of `info`, `warning`, or `error`.
- Used for UI tone, logs, and diagnostics.

`detail`

- Structured data needed to explain the state.
- Keep it small because firmware memory is limited.
- Prefer numbers, booleans, ids, and short enum strings.

`message`

- Optional transitional field.
- May be used for logs or temporary backward compatibility.
- UI logic must not depend on this field.
- New UI work should prefer i18n text generated from `code`.

---

## 6. Code Naming Rules

Use domain prefixes when possible.

Examples:

- `setup_wifi_connecting`
- `setup_wifi_connected`
- `setup_wifi_failed`
- `setup_ready`
- `setup_scan_started`
- `setup_scan_failed`
- `setup_ap_close_scheduled`
- `setup_ap_closing`
- `ha_handoff_started`
- `api_client_waiting`
- `api_client_connected`
- `api_client_idle`
- `calibration_ready`
- `calibration_pir_active`
- `calibration_max_zones_reached`
- `upload_started`
- `upload_committed`
- `upload_session_mismatch`
- `ota_uploading`
- `ota_reboot_waiting`
- `ota_device_reappeared`
- `debug_snapshot_ready`

Do not encode UI text into the code.

Bad:

- `pir_motion_detected_cannot_start_calibration`
- `please_wait_for_home_assistant_connection`

Better:

- `calibration_pir_active`
- `api_client_waiting`

---

## 7. Code Registry

This registry starts small on purpose. Add codes only when they are used by
firmware, dashboard, mock mode, or documented external behavior.

### 7.1 Common Error Codes

| Code | Severity | HTTP | Meaning | Detail |
|---|---|---:|---|---|
| `invalid_request` | error | 400 | Request shape or parameter is invalid. | `field`, `reason` |
| `unauthorized` | error | 401 | Required authentication is missing or invalid. | none |
| `forbidden` | error | 403 | Request is not allowed in the current state. | `reason` |
| `not_found` | error | 404 | Endpoint or resource does not exist. | `resource` |
| `conflict` | warning | 409 | Request conflicts with active state. | `reason` |
| `payload_too_large` | error | 413 | Request body exceeds the limit. | `maxBytes`, `receivedBytes` |
| `unsupported_media_type` | error | 415 | Unsupported content type. | `contentType` |
| `internal_error` | error | 500 | Unexpected internal failure. | `where` |
| `service_unavailable` | warning | 503 | Device is temporarily unavailable. | `reason`, `retryAfterMs` |

### 7.1.1 Device Configuration Codes

| Code | Severity | HTTP | Meaning | Detail |
|---|---|---:|---|---|
| `config_not_found` | error | 404 | Saved device configuration does not exist. | `target` |
| `config_write_failed` | error | 500 | Device configuration could not be written. | `target`, `where` |

### 7.2 Setup and Wi-Fi Codes

| Code | Severity | HTTP | Meaning | Detail |
|---|---|---:|---|---|
| `setup_wifi_connecting` | info | 200 | Wi-Fi connection attempt is in progress. | `ssid` |
| `setup_wifi_connected` | info | 200 | Wi-Fi connection succeeded. | `ssid`, `ip` |
| `setup_wifi_failed` | warning | 200 | Wi-Fi connection failed. | `ssid`, `reason` |
| `setup_ready` | info | 200 | Setup mode is ready for user action. | `stage` |
| `setup_scan_started` | info | 200 | Wi-Fi scan has started. | none |
| `setup_scan_failed` | error | 500 | Wi-Fi scan could not be started. | none |
| `setup_finish_pending` | info | 202 | Setup finish was accepted and is being applied. | none |
| `setup_ap_close_scheduled` | info | 200 | Setup AP close was scheduled after a grace period. | `delayMs` |
| `setup_ap_closing` | info | 202 | Setup AP is closing. | `delayMs` |
| `ha_handoff_started` | info | 200 | User-confirmed native API handoff has started. | `waitSeconds` |
| `api_client_waiting` | warning | 200 | Native API client has not connected yet. | `uptimeSeconds` |
| `api_client_connected` | info | 200 | Native API client is connected. | none |
| `api_client_idle` | info | 200 | Native API has no active client warning. | none |
| `api_key_ready` | info | 200 | API key is already customized and ready. | none |
| `api_key_rotated` | info | 200 | Default/demo API key was replaced. | none |
| `api_key_unavailable` | error | 503 | Native API key service is unavailable. | none |
| `api_key_not_set` | error | 404 | Native API key is not set. | none |
| `api_key_random_failed` | error | 500 | API key random generation failed. | none |
| `api_key_save_failed` | error | 500 | API key could not be saved. | none |
| `api_key_unsupported` | error | 503 | API key operation is unsupported in this build. | none |
| `wifi_unavailable` | error | 503 | Wi-Fi service is unavailable. | none |
| `wifi_not_ready` | warning | 409 | Wi-Fi STA configuration is not ready. | none |
| `wifi_unsupported` | error | 503 | Wi-Fi handoff is unsupported in this build. | none |
| `open_wifi_unsupported` | error | 400 | Open Wi-Fi networks are not supported. | none |
| `invalid_password_length` | error | 400 | Wi-Fi password length is outside the WPA range. | `min`, `max` |
| `boot_guard_active` | warning | 403 | Reset or OTA is blocked during initial boot guard. | `remainingSeconds` |

### 7.2.1 System Management Codes

| Code | Severity | HTTP | Meaning | Detail |
|---|---|---:|---|---|
| `nothing_selected` | warning | 400 | Reset request did not select any reset target. | `target` |
| `settings_reset_failed` | error | 500 | Settings reset failed. | `target` |
| `stats_reset_failed` | error | 500 | Statistics reset failed. | `target` |

### 7.2.2 Control API Codes

Control endpoints should use the common `invalid_request` code for invalid
request fields. Keep the legacy error string during migration, and put the
invalid `field` plus the affected `target` in `detail`.

| Endpoint group | Code | Severity | HTTP | Detail |
|---|---|---|---:|---|
| Control settings | `invalid_request` | error | 400 | `field`, `target` |

Timezone control uses the existing bounded control-request pattern.

Endpoints:

- `GET /api/control/status`
- `POST /api/control/timezone`
- `GET /api/control/static-radar-tuning`
- `POST /api/control/static-radar-tuning/session`
- `POST /api/control/static-radar-tuning/gate`

Rules:

- `POST /api/control/timezone` requires form field `data` containing a JSON
  object with a supported IANA `timezone` identifier.
- A successful change returns HTTP `200` with `changed: true` and
  `todayStatsReset: true`. Requesting the active timezone also returns HTTP
  `200`, with `changed: false`, and does not reset statistics. The change is
  applied asynchronously and its pending state is exposed by the status API.
- Applying a different timezone resets only the current-day counters and
  current-day heatmap. Completed daily history must be preserved.
- `GET /api/control/status` exposes `timezone`, `timezoneKnown`, and
  `timezoneApplyPending` so clients can wait for the asynchronous device-side
  apply operation.
- Unsupported timezone identifiers return the standard `invalid_request`
  envelope with `field: timezone` and `target: timezone`.

LD2410C tuning uses a short-lived engineering session so per-gate telemetry
does not run during normal operation.

- `GET /api/control/static-radar-tuning` always returns `available` and
  `active`. While inactive, `gates` is empty. While active, `gates` contains
  G0 through G8 with `startMm`, `endMm`, `sensitivity`, `moveEnergy`,
  and `stillEnergy`. Gate energy is tuning telemetry and must not be treated
  as a detected target position.
- `POST /api/control/static-radar-tuning/session` requires boolean `active`.
  An active request is also a keepalive. The firmware must leave engineering
  mode automatically when no active keepalive arrives for 15 seconds.
- Starting a session when LD2410C is unavailable returns HTTP `409` with code
  `static_radar_unavailable`.
- `POST /api/control/static-radar-tuning/gate` requires integer `gate` in
  `[0, 8]` and integer `sensitivity` in `[0, 100]`. The product-level
  sensitivity is translated to both LD2410C move and still thresholds as
  `threshold = 100 - sensitivity`.
- Gate writes are accepted only while the engineering session is active.
  Otherwise the endpoint returns HTTP `409` with code
  `static_radar_tuning_inactive`.
- Engineering telemetry is diagnostic only. It must not change presence,
  motion, target coordinates, target counts, zones, rooms, or heatmaps.

### 7.3 Upload Codes

| Code | Severity | HTTP | Meaning | Detail |
|---|---|---:|---|---|
| `upload_started` | info | 200 | Upload session has started. | `target`, `session`, `size` |
| `upload_committed` | info | 200 | Upload was committed successfully. | `target`, `session`, `size`, `hash` |
| `upload_session_mismatch` | error | 409 | Chunk does not match the active upload session. | `expected`, `received` |
| `upload_offset_mismatch` | error | 409 | Chunk offset does not match expected offset. | `expected`, `received` |
| `upload_incomplete` | error | 409 | Commit was requested before all bytes were received. | `expected`, `received` |
| `upload_payload_too_large` | error | 413 | Upload payload exceeds limit. | `maxBytes`, `receivedBytes` |
| `upload_storage_failed` | error | 500 | Upload could not be written or committed. | `target`, `where` |
| `firmware_upload_failed` | error | 500 | Firmware upload endpoint rejected or failed the upload. | optional legacy response text |
| `firmware_network_error` | error | 0 | Dashboard client lost the network while uploading firmware. | none |
| `firmware_upload_aborted` | warning | 0 | Dashboard client aborted the firmware upload. | none |

### 7.3.1 Device Config Upload

Device configuration writes should use the same chunked upload pattern as
floorplan and stats data because zone, floorplan, and future multi-sensor
settings can exceed safe single-form request sizes.

Endpoints:

- `POST /api/config/upload/start`
- `POST /api/config/upload/chunk`
- `POST /api/config/upload/commit`

Rules:

- `start` requires `session` and `size`.
- `chunk` requires `session`, `offset`, and hex-encoded `data`.
- `commit` requires `session`.
- `commit` must reload the stored device config into the firmware cache before
  returning success.
- Single-form legacy writes such as `POST /api/config`, `POST /api/stats`,
  `POST /api/floorplan`, and `POST /api/floorplan/image` are removed from the
  embedded API. Dashboard and restore flows must use the chunked upload
  endpoints.

### 7.3.2 Floorplan Patch Writes

Small floorplan edits may use dedicated single-form patch endpoints instead of
re-uploading the full floorplan document. These endpoints are intentionally
limited to bounded, low-memory fields and must not be used for image uploads,
room geometry replacement, wall segment replacement, object list replacement, or
full restore flows.

Endpoints:

- `POST /api/floorplan/radar`
- `POST /api/floorplan/room-name`
- `POST /api/floorplan/occlusion`
- `POST /api/floorplan/objects`

Rules:

- `POST /api/floorplan/radar` requires form field `data`, a JSON object with
  `originPx`, `rotationDeg`, and `scale`.
- `POST /api/floorplan/room-name` requires form fields `id` and `name`.
- `POST /api/floorplan/occlusion` requires form field `data`, a JSON object
  with `ignoredEdges`.
- `POST /api/floorplan/objects` requires form field `data`, a JSON array of
  floorplan furniture objects.
- The device updates the stored floorplan config payload in place and keeps the
  raw-partition metadata authoritative.
- If a patch target is missing, invalid, or too large, the device returns the
  standard error envelope with `invalid_request`, `not_found`, or
  `upload_storage_failed`.
- Full floorplan document writes, initial saves, restore flows, room geometry
  edits, scale edits, wall segment edits, and image writes must continue to use
  `POST /api/floorplan/upload/start|chunk|commit`.

### 7.4 Calibration Codes

| Code | Severity | HTTP | Meaning | Detail |
|---|---|---:|---|---|
| `calibration_ready` | info | 200 | Calibration can start. | none |
| `calibration_started` | info | 200 | Calibration run started. | none |
| `calibration_running` | info | 200 | Calibration is running. | `samples`, `zone` |
| `calibration_pir_active` | warning | 409 | PIR motion prevents calibration start. | `pir` |
| `calibration_no_target` | warning | 409 | Calibration cannot start because no target is detected. | none |
| `calibration_multiple_targets` | warning | 409 | Calibration cannot start because multiple targets are detected. | `targetCount` |
| `calibration_max_zones_reached` | warning | 409 | No more calibration zones can be created. | `maxZones` |
| `calibration_timeout` | error | 409 | Calibration ended without a stable candidate. | `samples`, `score` |
| `calibration_candidate_failed` | error | 500 | Calibration could not create a correction zone candidate. | `samples`, `score` |
| `calibration_saved` | info | 200 | Calibration zone was saved. | `zone`, `count` |

### 7.5 OTA Codes

| Code | Severity | HTTP | Meaning | Detail |
|---|---|---:|---|---|
| `ota_uploading` | info | 200 | OTA upload is in progress. | `bytesWritten`, `totalBytes` |
| `ota_reboot_waiting` | info | 202 | OTA upload completed and device is expected to reboot. | `retryAfterMs` |
| `ota_device_reappeared` | info | 200 | Device responded after OTA/reboot. | `version`, `buildTime` |
| `ota_verify_timeout` | warning | 503 | Device did not respond before timeout. | `timeoutMs` |

### 7.6 Debug Codes

| Code | Severity | HTTP | Meaning | Detail |
|---|---|---:|---|---|
| `debug_snapshot_ready` | info | 200 | Debug snapshot is available. | `timestamp` |
| `debug_events_ready` | info | 200 | Diagnostic event log is available. | `count`, `truncated`, `format` |
| `debug_events_empty` | info | 200 | Diagnostic event log is empty. | `format` |
| `debug_events_unavailable` | warning | 503 | Diagnostic event log is temporarily unavailable. | `resource` |
| `debug_replay_ready` | info | 200 | Presence replay log is available. | `count`, `truncated`, `format` |
| `debug_replay_empty` | info | 200 | Presence replay log is empty. | `format` |
| `debug_replay_unavailable` | warning | 503 | Presence replay log is temporarily unavailable. | `resource` |

---

## 8. Frontend Rules

The dashboard should prefer `status.code` or `error.code` and map it to i18n
messages.

Example:

```ts
const code = response.error?.code ?? response.status?.code ?? "unknown";
const text = messages.status[code] ?? messages.status.unknown;
```

Fallback policy:

1. Use `code` if present.
2. If `code` is missing, use the existing legacy field.
3. If no known field is available, show a generic message.

The frontend should not parse Korean or English sentences to decide behavior.

---

## 9. Firmware Rules

Firmware should provide compact status codes and details. It should avoid adding
more user-facing sentences to API responses unless needed for temporary
compatibility.

Firmware should avoid large diagnostic payloads in normal endpoints. Use a
dedicated debug endpoint when richer diagnostics are needed.

Debug endpoints that can return many records should stream or chunk their
responses instead of building one large string in firmware memory.

Shadow diagnostics may include experimental computed fields such as tracker
state, track score, observation counters, and recommended presence. These fields
must not replace the stable device state until the firmware behavior has been
verified in real installations.

`GET /api/state` may expose bounded LD2410C evidence under
`debug.staticRadar`. Its `available`, `presence`, `moving`, `still`, distance,
energy, and short `reason` fields describe sensor input. `detectionDistanceMm`
is the canonical LD2410C target distance stabilized with a three-sample median.
At most one distance sample per second enters the median window. Brief invalid
distance samples do not replace the last stable value; the history resets when
static-radar presence clears or the sensor becomes unavailable.
`movingDistanceMm` and
`stillDistanceMm` are diagnostic raw values and must not be combined by clients
to infer a target position. The nested `assist`
object reports whether presence assistance is armed, active, arming, or vetoed
by confirmed exit evidence. `debug.presenceEvidence` reports the independent
PIR, tracker, and static-assist evidence used by fusion.

LD2410C assistance may maintain an already established presence session, but it
must not start a new session by itself. PIR and confirmed LD2450 tracker
evidence remain the only acquisition inputs. LD2410C assistance must not create
motion, target coordinates, target counts, room state, or zone presence. A
confirmed `lost_after_exit` or `lost_after_room_exit` event must prevent a new
static hold for that drop event. Missing LD2410C hardware must behave as
`available: false` and preserve PIR plus LD2450 behavior.

Replay diagnostics may expose newline-delimited samples through a dedicated
debug endpoint. Replay payloads are for offline testing and must not be embedded
inside normal status responses.

Replay diagnostics may append compact optional tuples over time. Consumers must
ignore unknown fields and must provide safe defaults for missing optional fields.
For example, the `ex` tuple reports exit-zone evidence as
`[exitActive, exitZoneMask, exitTargetCount, exitLastSeenAgeMs]`.
The optional `sf` tuple reports fusion evidence and state as
`[pirEvidence, trackerEvidence, assistArmed, assistActive, armPending,
exitVeto, armElapsedMs]`.

---

## 10. Compatibility Policy

Existing fields must not be removed immediately.

Migration should follow this pattern:

1. Add `code`, `severity`, and `detail` beside the existing response.
2. Update mock/demo API to return the same fields.
3. Update frontend to prefer code-based messages.
4. Keep legacy fields until the new path is stable.
5. Remove legacy dependencies only after dashboard and firmware are verified.

---

## 11. Migration Priority

Recommended order:

1. Diagnostics/debug APIs
2. Calibration status
3. Floorplan upload status and errors
4. Setup and Wi-Fi handoff status
5. OTA upload and reboot confirmation status
6. `/api/system/status`

Reason:

- Debug and calibration are easiest to isolate.
- Upload/setup/OTA flows are more sensitive and should be changed after the
  pattern is proven.
- `/api/system/status` is widely consumed, so it should be changed carefully.

---

## 12. Configuration Enums

Software zone types:

| Value | Meaning |
| --- | --- |
| `detection` | Count targets inside the zone as zone presence. |
| `filter` | Treat targets inside the zone as false-positive candidates and block them. |
| `disabled` | Keep the zone in configuration but do not use it for detection. |
| `exit` | Mark a likely path where a person leaves the monitored area. This is exit evidence, not a filter. |

Calibration zone types:

| Value | Meaning |
| --- | --- |
| `filter` | Block repeated false-positive candidates. |
| `reduced` | Delay filtering before accepting a repeated candidate. |
| `disabled` | Keep the calibration zone in configuration but do not use it. |

`exit` is only a software zone type. It must not be treated as a calibration
zone type and must not remove targets by itself.

Presence engine flags:

| Field | Default | Meaning |
| --- | --- | --- |
| `legacyPresenceFallback` | `false` | Use the old lambda-based presence path instead of the tracker engine. This is a diagnostic fallback and must be explicitly enabled by the user. |

Older `trackerAssistPresence` values must not disable the tracker engine during
normal operation. Firmware should treat the tracker engine as the default unless
`legacyPresenceFallback` is explicitly `true`.

---

## 13. Do Not

Do not:

- Break existing API responses in one large change.
- Add new frontend logic that depends on display strings.
- Translate firmware messages directly in the API.
- Use long sentences as status codes.
- Put large logs into normal status responses.
- Change endpoint semantics while doing i18n work.
- Make peer devices exchange user-facing sentences.
- Merge coordinates from multiple sensors without explicit geometry setup.
- Use exit zones as filter zones.

---

## 14. Practical Rule for This Project

For now, new status-producing work should follow this rule:

```json
{
  "ok": true,
  "status": {
    "code": "feature_state",
    "severity": "info",
    "detail": {}
  }
}
```

Legacy string fields may remain, but new UI work should use `code` first.

---

## 15. LD2410C Presence Assistance Contract

`GET /api/state` exposes bounded LD2410C input and presence-assistance state
under `debug.staticRadar`. The `assist` object contains `armed`, `active`,
`armPending`, `armElapsedMs`, `exitVeto`, and the optional `heldTarget` snapshot.
Clients that display the LD2410C target position must use `presence` together
with the single `detectionDistanceMm` value.
`debug.presenceEvidence` reports PIR, LD2450 tracker, and LD2410C assistance as
independent evidence.

LD2410C may only maintain a presence session already acquired by PIR or a
confirmed LD2450 track. It must not acquire presence by itself and must not
create motion, active target coordinates or counts, room state, zone presence,
or heatmap samples. A current `lost_after_exit` or `lost_after_room_exit` drop
must veto a new static hold for that loss. Missing hardware is represented by
`available: false` and must preserve existing PIR plus LD2450 behavior.

While assistance is active, `assist.heldTarget` may preserve the last coordinate
of exactly one confirmed or coasting LD2450 track for display only. It is `null`
when no unambiguous prior spatial target exists. The snapshot does not make the
target active and consumers must not include it in target counts, zones, rooms,
calibration, or heatmaps.

```json
{
  "heldTarget": {
    "id": "target_1",
    "x": 600,
    "y": 1800,
    "lastDistanceMm": 1897,
    "staticDistanceMm": 1950,
    "distanceDeltaMm": 53,
    "distanceMatched": true
  }
}
```

`staticDistanceMm` and `distanceDeltaMm` are `null` when the stabilized
`detectionDistanceMm` is unavailable or invalid. `distanceMatched` is then
`false`. The dashboard may show a matched snapshot with the normal target
appearance and an unmatched snapshot as position-uncertain.

The optional replay `sr` tuple records static-radar evidence in this order:

```text
[available, presence, moving, still, movingDistanceMm, stillDistanceMm, movingEnergy, stillEnergy, detectionDistanceMm]
```

Readers must also accept legacy eight-item tuples and treat the missing
`detectionDistanceMm` as `0`.

The optional replay `sf` tuple records fusion state in this order:

```text
[pirEvidence, trackerEvidence, assistArmed, assistActive, armPending, exitVeto, armElapsedMs]
```

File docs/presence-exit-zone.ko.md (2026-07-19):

# 재실 퇴실 근거

이 문서는 LD2450 트랙이 사라질 때 production 재실 경로에서 사용하는 퇴실 근거를
설명한다. 퇴실 근거는 실제 퇴실 가능성과 정지·저움직임 사람의 일시적인 소실을
구분하는 데 사용한다.

## 1. 제품 규칙

```text
최근 퇴실 근거 이후 target이 사라짐
=> 짧은 퇴실 coasting 경로 사용

퇴실 근거 없이 target이 사라짐
=> 더 긴 비퇴실 coasting 경로 사용
```

퇴실 지점은 필터가 아니라 근거다. 타깃이 퇴실 지점에 들어갔다는 이유만으로
타깃을 제거하거나 관측 중인 재실을 끄지 않는다.

## 2. 사용자 설정

대시보드와 저장된 구역 모델은 다음 구역 타입을 지원한다.

```ts
type WebZoneType = "detection" | "filter" | "reduced" | "disabled" | "exit";
```

사용자는 문, 통로 또는 퇴실 가능성이 높은 경로에 선택적으로 퇴실 지점을 놓을 수
있다. 퇴실 지점이 하나도 없어도 기기는 동작한다.

## 3. 트래커 근거

필터링된 타깃 관측값은 퇴실 지점 bit mask를 `PresenceTracker`에 전달한다. 유지
중인 각 트랙은 마지막 mask와 시각을 기록한다. 최근 근거의 기본 유효 시간은
8초다.

평면도 방 정보가 있으면 트래커는 현재 방 polygon과의 signed distance도 본다.
신뢰할 수 있는 안쪽에서 바깥쪽으로의 통과는 방 퇴실 근거가 된다. 경계 근처에서
좌표가 흔들리는 것만으로 퇴실이 되지 않도록 Kalman 위치 covariance와 measurement
noise로 신뢰 margin을 계산한다.

## 4. 소실 동작

확정된 트랙이 관측을 잃으면 `coasting` 상태로 들어간다.

- 최근 설정된 퇴실 지점 근거가 있으면 짧은 퇴실 한도를 사용하고 만료 시
  `lost_after_exit`이 된다.
- 확인된 방 경계 통과는 `lost_after_room_exit`이 된다.
- 퇴실 근거가 없으면 `lost_without_exit`이 되고 더 긴 비퇴실 한도를 사용한다.
- 퇴실 지점 근처에 있지만 계속 관측되는 타깃은 일반 활성 트랙으로 유지된다.

missed-frame 기본 정책값은 현재 최근 퇴실 근거 4프레임, 일반/방 퇴실 경로
12프레임, 퇴실 지점 관측이 없을 때 24프레임이다. 이는 구현 기본값이며 API
보장값은 아니다.

## 5. 융합 영향

`PresenceFusion`은 현재 발생한 트래커 drop 이벤트만 소비한다. 새로운
`lost_after_exit` 또는 `lost_after_room_exit` 이벤트는 해당 소실의 LD2410C 보조를
막고 유지 중인 표시 좌표를 지운다. PIR 또는 확정된 LD2450이 다시 감지된 뒤에는
오래된 drop reason을 재사용하지 않는다.

LD2410C가 퇴실 여부를 판정하지는 않는다. 확인된 퇴실/filter veto가 없을 때 이미
armed된 세션을 유지할 수 있을 뿐이다.

## 6. 진단과 리플레이

`/api/state`, 진단 로그와 리플레이 데이터는 퇴실 mask, 최근 퇴실 경과 시간, 방
상태, 트래커 drop reason과 융합 exit veto를 노출한다. 네이티브 테스트는 다음을
다룬다.

- 설정된 퇴실 지점 이후 소실;
- 방 안쪽에서 바깥쪽으로의 경계 통과;
- 경계 통과 없는 소실;
- 재획득 이후 오래된 drop 이벤트;
- 퇴실 또는 filter 근거가 LD2410C 재진입을 막는 동작.

## 7. 경계

- 퇴실 지점은 filter zone처럼 동작하면 안 된다.
- 온보딩에서 퇴실 설정을 필수로 만들면 안 된다.
- 퇴실 판정에 다중 센서, Home Assistant 또는 BLE 근거를 요구하지 않는다.
- coasting 기본값을 바꾸기 전에 실제 설치 리플레이를 검토한다.

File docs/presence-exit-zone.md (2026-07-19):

# Presence Exit Evidence

This document describes the production exit evidence used when an LD2450 track
disappears. Exit evidence helps distinguish a likely departure from a temporary
loss of a still or low-motion person.

## 1. Product Rule

```text
target disappears after recent exit evidence
=> use the short exit coasting path

target disappears without exit evidence
=> use the longer non-exit coasting path
```

Exit areas are evidence, not filters. Entering an exit area does not remove a
target and does not turn presence off while the target is still observed.

## 2. User Configuration

The dashboard and stored zone model support these zone types:

```ts
type WebZoneType = "detection" | "filter" | "reduced" | "disabled" | "exit";
```

Users may place optional exit areas over doors, passages, or other likely
departure paths. A device continues to work without any configured exit area.

## 3. Tracker Evidence

Filtered target observations carry an exit-zone bit mask into
`PresenceTracker`. Each retained track records its latest mask and timestamp.
The default recent-evidence window is 8 seconds.

When floorplan room context is available, the tracker also watches signed
distance from the current room polygon. A confident inside-to-outside crossing
creates room-exit evidence. The confidence margin comes from Kalman position
covariance plus measurement noise so a point hovering near the boundary is not
treated as an exit by itself.

## 4. Drop Behavior

When a confirmed track loses observations it enters `coasting`.

- Recent configured exit-zone evidence uses the short exit limit and produces
  `lost_after_exit` when the track expires.
- Confirmed room-boundary crossing produces `lost_after_room_exit`.
- No exit evidence produces `lost_without_exit` and uses the longer non-exit
  limit.
- A target observed near an exit but not crossing or disappearing remains a
  normal active track.

The default missed-frame limits are policy values, currently 4 for recent exit
evidence, 12 for the general/room-exit path, and 24 when no exit zone has been
seen. They are implementation defaults rather than API guarantees.

## 5. Fusion Effect

`PresenceFusion` consumes only current tracker drop events. A new
`lost_after_exit` or `lost_after_room_exit` event vetoes LD2410C assistance for
that loss and clears any retained display coordinate. Stale drop reasons are
not reused after PIR or confirmed LD2450 reacquisition.

LD2410C does not decide whether a departure occurred. It can only maintain an
already armed session when no confirmed exit/filter veto is active.

## 6. Diagnostics and Replay

`/api/state`, diagnostic logs, and replay data expose exit masks, recent exit
age, room state, tracker drop reason, and fusion exit veto. Native tests cover:

- disappearance after a configured exit area;
- inside-to-outside room-boundary crossing;
- disappearance without crossing;
- stale drop events after reacquisition;
- LD2410C reentry blocked by exit or filter evidence.

## 7. Boundaries

- Exit areas must not behave like filter zones.
- Exit setup must remain optional during onboarding.
- Multi-sensor, Home Assistant, and BLE evidence are not required for an exit
  decision.
- Real installation replay data should be reviewed before changing coasting
  defaults.

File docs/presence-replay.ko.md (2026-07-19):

# 재실 리플레이 계획

이 문서는 재실 감지 신뢰성 개선을 위한 테스트 흐름을 정의한다.
목표는 사람이 센서 앞에 오래 앉아 있는 방식에서 벗어나, 같은 입력을 반복
재생하고 점수화할 수 있게 만드는 것이다.

이 문서는 설계 문서이며 production 동작을 변경하지 않는다.

## 1. 목표

tracker를 수정할 때마다 사람이 직접 10분씩 앉아 있는 방식은 반복성이 낮고
시간이 너무 많이 든다.

리플레이 테스트는 다음 질문에 답할 수 있어야 한다.

- 사람이 있는데 재실이 꺼졌는가?
- 사람이 없는데 재실이 켜졌는가?
- 작은 움직임 중 target identity 또는 tracker state가 쪼개졌는가?
- motion/still/direction 상태가 너무 자주 튀는가?
- 새 tracker 변경이 한 케이스를 개선하면서 다른 케이스를 망가뜨렸는가?

## 2. 테스트 계층

### 2.1 펌웨어 Smoke Test

실기기 테스트는 여전히 필요하지만 작게 유지한다.

확인 대상:

- 펌웨어가 부팅되는지
- API가 응답하는지
- 진단 로그 다운로드가 되는지
- 근거리 명확한 상황에서 재실 감지가 되는지
- 크래시나 rollback loop가 없는지

이 방식은 tracker 튜닝의 주 테스트 수단이 아니다.

### 2.2 실제 로그 리플레이

기기는 PC로 내려받아 재생할 수 있는 compact raw replay log를 기록한다.

리플레이 로그는 이벤트 요약만이 아니라 tracker 동작을 다시 구성할 수 있는
입력 신호를 포함해야 한다.

Endpoint:

```text
GET /api/diagnostics/replay.ndjson
```

endpoint는 newline-delimited JSON을 반환한다. 실패 응답은
`docs/api-contract.md`를 따른다.

각 줄은 sampling tick 하나를 나타낸다. 가능하면 production presence tick과
같은 주기를 사용한다.

Compact row 예시:

```json
{"q":12,"t":123456,"p":0,"lx":50.2,"r":[[1,1240,1810,2,2195,0,0,1],[0,0,0,0,0,0,0,0],[0,0,0,0,0,0,0,0]],"tg":[[1,1240,1810,2,2195],[0,0,0,0,0],[0,0,0,0,0]],"sr":[1,1,0,1,0,1850,0,67,1850],"sf":[0,0,1,1,0,0,0],"f":[0,0,0,0,0],"ex":[0,0,0,-1],"l":[1,0,1,1,0,1,82,0,9,0,3,2,4],"tr":[0,0,0,0,0,0,0,0,0,0,0,0]}
```

최소 필드:

- `q`: sample sequence
- `t`: 장치 uptime milliseconds
- `p`: PIR motion 상태
- `lx`: 가능하면 조도
- `r`: software/reduced/range filtering 전 LD2450 target slot 최대 3개
  Target tuple: `[valid, x, y, speed, distance, filterMode, filtered, rangeValid]`
- `tg`: 현재 production filter/range-gate 경로를 지난 target slot 최대 3개
  Target tuple: `[valid, x, y, speed, distance]`
- `sr`: 선택적인 LD2410C 정적 레이더 입력 tuple
  `[available, presence, moving, still, movingDistanceMm, stillDistanceMm, movingEnergy, stillEnergy, detectionDistanceMm]`
  마지막 필드는 재실 융합과 대시보드 위치 표시에 사용하는 안정화된 기준 거리다.
  기존 8개짜리 튜플도 계속 읽으며 이 경우 `detectionDistanceMm`은 `0`으로 처리한다.
- `sf`: 선택적인 재실 융합 tuple
  `[pirEvidence, trackerEvidence, assistArmed, assistActive, armPending, exitVeto, armElapsedMs]`
  기존 로그에 이 tuple이 없으면 모든 값을 0으로 처리한다.
- `f`: filter/range tuple:
  `[filterBlocked, rangeReasonCode, suspectCount, outOfRangeCount, remoteCandidateCount]`
- `ex`: exit zone evidence tuple:
  `[exitActive, exitZoneMask, exitTargetCount, exitLastSeenAgeMs]`
- `l`: production 재실 출력 tuple:
  `[presence, motion, still, targetCount, movingCount, stillCount, stillConfidence, emptySamples,
  presenceReasonCode, presenceOffReasonCode, motionReasonCode, stillStateCode, stillReasonCode]`
- `tr`: tracker tuple:
  `[presence, motion, stateCode, reasonCode, score, inputCount, activeCount, tentativeCount,
  confirmedCount, coastingCount, movingCount, stillCount]`

리플레이 로그는 RAM 전용이다. 사용자 설정이 아니라 진단 데이터다.

### 2.3 Ground Truth 라벨

실제 로그에는 사람이 짧게 정답 구간을 적는다.

예시:

```json
{
  "segments": [
    {"from": "21:18:00", "to": "21:25:30", "occupied": true, "note": "책상에 앉아있음"},
    {"from": "21:25:30", "to": "21:40:00", "occupied": false, "note": "빈 방"}
  ]
}
```

첫 버전은 occupancy truth만 있으면 된다. 정확한 좌표 정답까지는 필요 없다.

나중에 추가할 수 있는 라벨:

- `zone`: desk, bed, bathroom, entrance 등
- `activity`: sitting, eating, walking, sleeping, cleaning robot, empty
- `sensor`: room, bathroom, 또는 multi-sensor primary coordinator

## 3. 점수화

리플레이 도구는 replay output을 ground truth와 비교해서 숫자로 보여줘야 한다.

초기 지표:

- `false_off_count`: 사람이 있는데 재실이 꺼진 횟수
- `false_off_seconds`: 사람이 있는데 재실이 꺼진 총 시간
- `false_on_count`: 빈 방인데 재실이 켜진 횟수
- `false_on_seconds`: 빈 방인데 재실이 켜진 총 시간
- `presence_fragment_count`: occupied 상태에서 on/off가 쪼개진 횟수
- `reacquire_latency_ms`: target 재등장 또는 PIR hint 후 재실 회복 시간
- `motion_flip_count`: motion on/off 전환 횟수
- `still_flip_count`: still confirmed/lost 전환 횟수
- `tracker_state_flip_count`: tracker lifecycle 전환 횟수
- `target_drop_count`: truth는 occupied인데 radar target이 모두 사라진 tick 수

나중에는 multi-object tracking 평가에서 쓰는 개념을 일부 가져올 수 있다.

- miss와 false positive
- ID switch와 fragmentation
- 좌표 ground truth가 생기면 localization error

## 4. 리플레이 도구 형태

PC 리플레이 및 네이티브 트래커 도구는 다음 경로에 있다.

```text
tools/presence-replay/
```

현재 사용할 수 있는 명령:

```text
python tools/presence-replay/replay.py logs/replay.ndjson --truth logs/truth.json
python tools/presence-replay/test_replay.py
python tools/presence-replay/native/test.py
python tools/presence-replay/native/build.py
```

`replay.py`는 기존 펌웨어 출력을 점수화한다. 네이티브 명령은 `cl`, `g++`,
`clang++` 중 하나를 사용해 트래커 실행기와 단위 테스트를 컴파일한다.

네이티브 실행기는 현재 Kalman 기반 트래커를 실행한다. 향후 policy 또는 noise model
후보를 비교할 수 있지만 리플레이 파일의 하위 호환성은 유지해야 한다.

## 5. 펌웨어 경계

펌웨어는 compact replay sample을 모으고 다운로드하게 해주는 역할만 한다.

Monte Carlo 시뮬레이션은 펌웨어 안에서 돌리지 않는다.

500 ms lambda는 커지면 안 된다. 현재 sample을 전용 diagnostics component로
넘기는 역할만 한다.

## 6. 현재 상태

펌웨어 ring buffer, 진단 endpoint, 대시보드 다운로드, PC scorer, 네이티브 트래커
실행기와 단위 테스트가 구현되어 있다. 시나리오 및 Monte Carlo 도구는 선택적인
후속 작업이다. production 트래커를 변경할 때는 계속 실제 리플레이 데이터로
회귀를 확인한다.

## 7. LD2410C 융합 필드

`sr` 튜플은 LD2410C 센서 입력을 기록한다.

```text
[available, presence, moving, still, movingDistanceMm, stillDistanceMm, movingEnergy, stillEnergy, detectionDistanceMm]
```

`sf` 튜플은 재실 융합 상태를 기록한다.

```text
[pirEvidence, trackerEvidence, assistArmed, assistActive, armPending, exitVeto, armElapsedMs]
```

기존 8개짜리 `sr` 튜플은 `detectionDistanceMm`을 0으로 처리하고, `sf`가 없는
기존 리플레이 파일은 모든 융합 값을 0으로 처리한다. LD2410C 보조는 이미 시작된
재실을 유지할 수 있다. 안정화 거리는 마지막으로 명확했던 LD2450 위치의 표시
신뢰도만 판단하며, 단독으로 재실·움직임·새 공간 위치를 만들지 않는다.

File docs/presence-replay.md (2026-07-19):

# Presence Replay

This document defines the test workflow for presence reliability work.
The goal is to stop relying on long manual sitting tests and move toward
repeatable replay, scoring, and simulation.

Replay diagnostics record production inputs and outputs but do not change
production behavior by themselves.

## 1. Goal

The device should be tested with repeatable input streams instead of requiring a
person to sit in front of the sensor for every tracker change.

The replay workflow should answer questions such as:

- Did presence turn off while the room was occupied?
- Did presence stay on while the room was empty?
- Did target identity or tracker state fragment during small motion?
- Did motion/still/direction states flap too often?
- Did a proposed tracker change improve one case while breaking another?

## 2. Test Layers

### 2.1 Firmware Smoke Test

This remains necessary, but it should be small.

Use it to confirm:

- The firmware boots.
- The API remains responsive.
- Diagnostics download works.
- Presence still works in obvious near-field cases.
- No crash or rollback loop appears.

This should not be the main way to tune tracker behavior.

### 2.2 Real Log Replay

The device captures a compact raw replay log that can be downloaded and
replayed on a PC.

The replay log must include the input signals needed to reconstruct tracker
behavior, not only event summaries.

Endpoint:

```text
GET /api/diagnostics/replay.ndjson
```

The endpoint returns newline-delimited JSON. If the endpoint fails, it
must follow `docs/api-contract.md`.

Each row should represent one sampling tick. The preferred interval is the same
as the production presence tick.

Example compact row:

```json
{"q":12,"t":123456,"p":0,"lx":50.2,"r":[[1,1240,1810,2,2195,0,0,1],[0,0,0,0,0,0,0,0],[0,0,0,0,0,0,0,0]],"tg":[[1,1240,1810,2,2195],[0,0,0,0,0],[0,0,0,0,0]],"sr":[1,1,0,1,0,1850,0,67,1850],"sf":[0,0,1,1,0,0,0],"f":[0,0,0,0,0],"ex":[0,0,0,-1],"l":[1,0,1,1,0,1,82,0,9,0,3,2,4],"tr":[0,0,0,0,0,0,0,0,0,0,0,0]}
```

Minimum fields:

- `q`: sample sequence.
- `t`: device uptime in milliseconds.
- `p`: PIR motion state.
- `lx`: illuminance if available.
- `r`: up to three LD2450 target slots before software/reduced/range filtering.
  Target tuple: `[valid, x, y, speed, distance, filterMode, filtered, rangeValid]`.
- `tg`: up to three target slots after the current production filter/range-gate path.
  Target tuple: `[valid, x, y, speed, distance]`.
- `sr`: optional LD2410C static-radar input tuple:
  `[available, presence, moving, still, movingDistanceMm, stillDistanceMm, movingEnergy, stillEnergy, detectionDistanceMm]`.
  The final field is the canonical stabilized distance used by presence fusion
  and dashboard positioning. Legacy eight-item tuples remain valid and decode
  `detectionDistanceMm` as `0`.
- `sf`: optional presence-fusion tuple:
  `[pirEvidence, trackerEvidence, assistArmed, assistActive, armPending, exitVeto, armElapsedMs]`.
  Missing tuples default to zeros so older replay files remain valid.
- `f`: filter/range tuple:
  `[filterBlocked, rangeReasonCode, suspectCount, outOfRangeCount, remoteCandidateCount]`.
- `ex`: exit-zone evidence tuple:
  `[exitActive, exitZoneMask, exitTargetCount, exitLastSeenAgeMs]`.
- `l`: production presence-output tuple:
  `[presence, motion, still, targetCount, movingCount, stillCount, stillConfidence, emptySamples,
  presenceReasonCode, presenceOffReasonCode, motionReasonCode, stillStateCode, stillReasonCode]`.
- `tr`: tracker tuple:
  `[presence, motion, stateCode, reasonCode, score, inputCount, activeCount, tentativeCount,
  confirmedCount, coastingCount, movingCount, stillCount]`.

The replay log is RAM-only. It is diagnostic data, not user configuration.

### 2.3 Ground Truth Labels

For real logs, ground truth should be written manually as short segments.

Example:

```json
{
  "segments": [
    {"from": "21:18:00", "to": "21:25:30", "occupied": true, "note": "sitting at desk"},
    {"from": "21:25:30", "to": "21:40:00", "occupied": false, "note": "room empty"}
  ]
}
```

The first version only needs occupancy truth. Exact target coordinates are not
required.

Optional future labels:

- `zone`: desk, bed, bathroom, entrance, etc.
- `activity`: sitting, eating, walking, sleeping, cleaning robot, empty.
- `sensor`: room, bathroom, or primary coordinator in multi-sensor tests.

## 3. Scoring

The replay tool should compare replay output against ground truth and produce
numbers.

Initial metrics:

- `false_off_count`: number of occupied segments where presence turned off.
- `false_off_seconds`: total time presence was off while occupied.
- `false_on_count`: number of empty segments where presence turned on.
- `false_on_seconds`: total time presence was on while empty.
- `presence_fragment_count`: number of on/off fragments during occupied time.
- `reacquire_latency_ms`: time from target reappearance or PIR hint to presence.
- `motion_flip_count`: number of motion on/off transitions.
- `still_flip_count`: number of still confirmed/lost transitions.
- `tracker_state_flip_count`: number of tracker lifecycle transitions.
- `target_drop_count`: number of ticks where all radar targets disappeared while
  truth was still occupied.

Later metrics can borrow ideas from multi-object tracking evaluation:

- Misses and false positives from CLEAR MOT.
- ID switches and fragmentation.
- Localization error if coordinate ground truth becomes available.

## 4. Replay Tool Shape

The PC replay and native tracker tools live under:

```text
tools/presence-replay/
```

Available commands:

```text
python tools/presence-replay/replay.py logs/replay.ndjson --truth logs/truth.json
python tools/presence-replay/test_replay.py
python tools/presence-replay/native/test.py
python tools/presence-replay/native/build.py
```

`replay.py` scores existing firmware output. The native commands compile the
tracker runner and unit tests with `cl`, `g++`, or `clang++`.

The native runner executes the current Kalman-based tracker. Future experiments
may compare policy or noise-model variants, but replay files must remain
backward compatible.

## 5. Firmware Boundary

The firmware should only collect compact replay samples and expose downloads.

It should not run Monte Carlo simulation.

The 500 ms lambda should not grow. It only passes the current sample to the
dedicated diagnostics component.

## 6. Current Status

The firmware ring buffer, diagnostics endpoint, dashboard download, PC scorer,
native tracker runner, and native unit tests are implemented. Scenario and
Monte Carlo tools remain optional follow-up work. Production tracker changes
should continue to be checked against captured replay data.

## 7. LD2410C Fusion Fields

The `sr` tuple records LD2410C sensor input and the stabilized distance used by
the current fusion path:

```text
[available, presence, moving, still, movingDistanceMm, stillDistanceMm, movingEnergy, stillEnergy, detectionDistanceMm]
```

Legacy eight-item `sr` tuples default `detectionDistanceMm` to zero. The `sf`
tuple records fusion state:

```text
[pirEvidence, trackerEvidence, assistArmed, assistActive, armPending, exitVeto, armElapsedMs]
```

Replay files without `sf` default every fusion field to zero. LD2410C
assistance may maintain an already established presence session. Its stabilized
distance may only evaluate display confidence for the last unambiguous LD2450
position; it cannot acquire presence, motion, or a new spatial position by
itself.

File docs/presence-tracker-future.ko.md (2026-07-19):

# 재실 트래커 향후 작업

향후 작업도 현재 획득 경계를 유지해야 한다. PIR과 LD2450은 재실을 시작할 수
있지만 선택적인 LD2410C 보조는 이미 시작된 세션만 유지할 수 있다.

## 다음 검증 단계

1. 여러 설치 환경에서 수면, 책상 작업, 빈방, 선풍기, 냉난방 및 확인된 퇴실
   리플레이를 수집한다.
2. 개별 사례가 아니라 해당 로그를 기준으로 Kalman noise, association 범위와
   coasting 한도를 조정한다.
3. 짧은 알 수 없음 값을 견디는 현재 동작은 유지하면서, LD2410C 거리값이 장시간
   유효하지 않을 때 expiry가 필요한지 측정한다.
4. held-target 거리 허용치 750mm를 방 크기, 설치 방향과 근접한 다중 레이더
   환경에서 검증한다.
5. production 기본값을 바꾸기 전에 false-off 시간, false-on 시간, fragmentation과
   재획득 지연을 비교한다.

## 별도 기능

- BLE nearby 근거는 선택 사항이어야 하며 조용히 필수 획득 근거가 되어서는 안 된다.
- 수면 시간 설정은 암묵적인 트래커 휴리스틱이 아니라 명시적인 제품 모드로 다룬다.
- 다중 기기 조정은 이 트래커가 아니라
  [multi-sensor-contract.ko.md](multi-sensor-contract.ko.md)에서 다룬다.

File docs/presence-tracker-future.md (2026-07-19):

# Presence Tracker Future Work

Future work must preserve the current acquisition boundary: PIR and LD2450 may
start presence, while optional LD2410C assistance may only maintain an already
established session.

## Next Validation Steps

1. Collect replay logs from sleeping, desk work, empty rooms, fans, HVAC, and
   confirmed exits across several installations.
2. Tune Kalman noise, association gates, and coasting limits from those logs
   instead of individual anecdotes.
3. Measure whether a sustained invalid LD2410C distance needs an expiry while
   preserving the current protection against brief unknown values.
4. Validate the 750 mm held-target distance tolerance against room size,
   orientation, and close multi-radar installations.
5. Compare false-off time, false-on time, fragmentation, and reacquisition
   latency before changing production defaults.

## Separate Features

- BLE nearby evidence must remain optional and must not silently become a
  required acquisition source.
- Sleep schedules should be a product mode with explicit user behavior, not an
  implicit tracker heuristic.
- Multi-device coordination belongs to
  [multi-sensor-contract.md](multi-sensor-contract.md), not this tracker.

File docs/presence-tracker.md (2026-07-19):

# Presence Tracker and Fusion

This document describes the production presence path between filtered LD2450
observations and the final presence and motion outputs.

## 1. Runtime Path

- The tracker path is enabled by default. The legacy lambda path remains an
  explicit fallback through the advanced legacy-presence setting.
- The 500 ms ESPHome lambda passes filtered LD2450 observations, PIR state,
  room/exit evidence, and optional LD2410C evidence into C++ components.
- `PresenceTracker` owns LD2450 track identity, lifecycle, position, velocity,
  direction, room crossing, and exit evidence.
- `PresenceFusion` combines PIR and tracker evidence and may use an optional
  LD2410C only to maintain a session that PIR or a confirmed LD2450 track
  already established.
- Outputs are exposed through `/api/state`, Home Assistant entities,
  diagnostics, and replay logs.

## 2. LD2450 Tracking

The tracker handles at most three observations and retained tracks, matching
the LD2450 hardware limit. It evaluates the small set of possible assignments
directly instead of using a general Hungarian implementation.

Tracks move through these states:

- `tentative`: awaiting enough recent observations.
- `confirmed`: contributes directly to presence and moving/still counts.
- `coasting`: temporarily retained after observations disappear.
- `idle`: unused slot.

Position and velocity use a constant-velocity Kalman filter with bounded time
steps, process noise, measurement noise, and covariance. A large teleport-like
measurement resets the filter instead of dragging the previous estimate across
the room. Confirmed and coasting tracks use a wider reassociation gate than new
tentative tracks.

`trackScore` is a bounded diagnostic score derived from recent hits, misses,
and lifecycle state. It is not a probability or a user-facing confidence
percentage.

## 3. Exit and Room Evidence

Each track records recent exit-zone hits and room-boundary state.

- A recent configured exit-zone hit can shorten coasting and produce
  `lost_after_exit`.
- A confident inside-to-outside room-boundary crossing can produce
  `lost_after_room_exit`.
- A disappearance without either signal produces `lost_without_exit` and uses
  the longer non-exit coasting policy.
- `filter_blocked` remains a missed-observation frame and does not reset every
  track immediately.

Current drop events are consumed by `PresenceFusion`. Confirmed exit drops veto
a new LD2410C hold for that loss event.

## 4. Presence Fusion

PIR and LD2450 are complementary acquisition evidence. Either PIR motion or a
confirmed/coasting tracker result can keep the base presence path active;
motion is the OR of PIR motion and tracker motion unless filtering blocks it.

LD2410C assistance follows these rules:

- Missing hardware is ignored through `available: false`.
- Static radar alone cannot start presence, motion, target counts, room state,
  zone state, or heatmap samples.
- Static presence must overlap an existing PIR/tracker session for 2 seconds
  before assistance is armed.
- When LD2450 disappears without confirmed exit evidence, an armed LD2410C may
  maintain presence.
- After stable presence ends without exit/filter veto, one 30-second reentry
  window allows the already armed assistance to recover that same session.
- PIR or LD2450 reacquisition resumes normal combined evidence without a
  primary/secondary sensor switch.

For display only, assistance may retain the last coordinate of exactly one
unambiguous confirmed or coasting LD2450 track. This retained coordinate does
not become an active target and is excluded from counts, zones, rooms,
calibration, and heatmaps.

## 5. Static Distance Stabilization

`detectionDistanceMm` is the only LD2410C distance used for held-target display
confidence.

- At most one valid sample per second enters a three-sample median window.
- The first valid sample is available immediately.
- A single spike cannot replace the stable value.
- Brief invalid distance samples retain the last stable value while static
  presence remains active.
- Static presence clear or sensor unavailability resets the distance history.
- Moving/still distances and energies remain raw diagnostic telemetry and are
  not combined to infer position.

## 6. Validation and Limits

- Native tests cover lifecycle, assignment, Kalman smoothing, exit/room drops,
  fusion arming, exit veto, reentry, missing hardware, held-target confidence,
  and distance stabilization.
- Replay logs distinguish raw observations, production-filtered observations,
  tracker output, exit evidence, static-radar input, and fusion state.
- BLE nearby and sleep schedules are not acquisition inputs.
- Track policy constants and LD2410C distance matching still require validation
  against varied real installations.

Future experiments live in
[presence-tracker-future.md](presence-tracker-future.md).

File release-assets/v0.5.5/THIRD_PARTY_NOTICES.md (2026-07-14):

# Third-Party Notices

This file is generated by `scripts/generate-third-party-notices.mjs`. Do not edit it manually.

NAMO's own software and firmware are licensed under AGPL-3.0-or-later. The components below retain their respective copyrights and licenses. Full license texts used by the distributed runtime are collected in [THIRD_PARTY_LICENSES.txt](THIRD_PARTY_LICENSES.txt).

## Included in the Firmware

### ESPHome 2026.5.1

- Upstream: https://github.com/esphome/esphome
- License: GPL-3.0 and MIT
- Use: ESPHome's C++ runtime is compiled into the firmware. Its Python tooling is used during the build and is not embedded in the device image.

ESPHome's upstream license applies GPLv3 to its C++ runtime and MIT to its Python code and other parts. See the complete ESPHome license notice in `THIRD_PARTY_LICENSES.txt`.

### Espressif ESP-IDF 5.5.4

- PlatformIO package version: 3.50504
- Upstream: https://github.com/espressif/esp-idf
- License: Apache-2.0 with component-specific exceptions
- Use: framework and runtime components compiled into the ESP32-S3 firmware.

ESP-IDF's top-level license is Apache-2.0. Individual components may carry compatible component-specific licenses; their upstream notices remain authoritative for those components.

## ESP-IDF Managed Components Included in the Firmware

### ArduinoJson 7.4.2

- Upstream: https://github.com/bblanchon/ArduinoJson
- License: MIT
- Use: ESP-IDF managed component compiled into the ESP32-S3 firmware.

### Espressif mDNS 1.11.0

- Upstream: https://github.com/espressif/esp-protocols/tree/master/components/mdns
- License: Apache-2.0
- Use: ESP-IDF managed component compiled into the ESP32-S3 firmware.

### multipart-parser 1.0.1

- Upstream: https://github.com/zorxx/multipart-parser
- License: MIT
- Use: ESP-IDF managed component compiled into the ESP32-S3 firmware.

## Included in the Embedded Dashboard

### Svelte 5.56.3

- Upstream: https://github.com/sveltejs/svelte
- License: MIT
- Use: runtime code included in the generated dashboard JavaScript bundle.

## Loaded at Runtime for Optional OCR

The following files are not embedded in the firmware. When the floorplan OCR feature is used, the browser downloads them directly from the listed CDN services and performs recognition locally in the browser.

### Tesseract.js 6.0.1

- Upstream: https://github.com/naptha/tesseract.js
- License: Apache-2.0
- CDN: https://cdn.jsdelivr.net/npm/tesseract.js@6.0.1/dist/tesseract.min.js
- Worker: https://cdn.jsdelivr.net/npm/tesseract.js@6.0.1/dist/worker.min.js

### Tesseract.js Core 6.0.0

- Upstream: https://github.com/naptha/tesseract.js-core
- License: Apache-2.0
- CDN: https://cdn.jsdelivr.net/npm/tesseract.js-core@6.0.0

### Project Naptha tessdata 4.0.0

- Upstream: https://github.com/naptha/tessdata
- License: Apache-2.0
- CDN: https://tessdata.projectnaptha.com/4.0.0

## Build and Test Tooling

The npm packages used only to build, lint, format, and test the dashboard are recorded with their resolved versions and license identifiers in `dashboard/package-lock.json`. They are not copied into the embedded dashboard unless the bundler includes runtime code from them.

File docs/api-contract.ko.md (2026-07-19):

# API 계약

이 문서는 기기 API가 상태, 오류, 사용자 표시 문구를 어떤 방식으로 표현해야 하는지
정리한다. 목적은 펌웨어, 대시보드 UI, 데모 모드, 향후 외부 연동이 늘어나도 서로
덜 꼬이게 만드는 것이다.

이 문서는 완전한 OpenAPI 스펙이 아니다. 이 프로젝트에서 실제로 지킬 수 있는
실용적인 API 계약이다.

---

## 1. 적용 범위

이 계약은 우선 상태나 오류 정보를 반환하는 API부터 적용한다. 기존 API를 한 번에
전부 바꾸지 않는다.

초기 적용 대상:

- `/api/system/status`
- `/api/setup/*`
- `/api/state`의 `debug.staticRadar`는 제한된 크기의 LD2410C 입력과 재실 보조 상태를 제공한다.
  `available`, `presence`, `moving`, `still`, 거리, 에너지 및 짧은 `reason`은 센서 입력이며,
  `assist`는 이미 시작된 재실을 유지하는 융합 상태를 제공한다.
- 평면도 업로드 API
- 통계 업로드 및 백업/복원 API
- 보정 관련 API
- OTA 업로드 및 재응답 확인 흐름
- 진단 및 디버그 API

---

## 2. 핵심 원칙

API는 프로그램이 판단할 수 있는 안정적인 코드를 반환하고, 실제 표시 문구는
프론트엔드가 언어 설정에 맞춰 만든다.

권장:

```json
{
  "ok": false,
  "error": {
    "code": "calibration_pir_active",
    "severity": "warning",
    "detail": {
      "pir": true
    }
  }
}
```

새 API에서는 피할 것:

```json
{
  "ok": false,
  "status": "PIR 움직임이 감지되어 시작할 수 없습니다."
}
```

---

## 3. 응답 구조

### 3.1 성공 응답

성공 응답은 반드시 `ok: true`를 사용한다.

권장 형태:

```json
{
  "ok": true,
  "data": {},
  "status": {
    "code": "ready",
    "severity": "info",
    "detail": {}
  }
}
```

규칙:

- `ok`는 반드시 `true`다.
- `data`에는 실제 도메인 데이터를 넣는다.
- 전달할 상태가 없다면 `status`는 생략해도 된다.
- `status`가 있다면 `status.code`는 안정적인 기계 판독용 값이어야 한다.
- 실패 원인을 `status`에 넣지 않는다.

### 3.2 실패 응답

실패 응답은 반드시 `ok: false`를 사용한다.

권장 형태:

```json
{
  "ok": false,
  "error": {
    "code": "upload_session_mismatch",
    "severity": "error",
    "detail": {
      "expected": 2,
      "received": 0
    }
  }
}
```

규칙:

- `ok`는 반드시 `false`다.
- 실패 원인은 `error.code`에 넣는다.
- `error.severity`는 `warning` 또는 `error`를 사용한다.
- `error.detail`에는 작고 구조화된 데이터만 넣는다.
- UI 로직은 `error.message`에 의존하면 안 된다.

### 3.3 진행 중 응답

시간이 걸리거나 나중에 완료되는 작업은 `ok: true`와 status code를 반환한다.

예시:

```json
{
  "ok": true,
  "status": {
    "code": "ota_reboot_waiting",
    "severity": "info",
    "detail": {
      "retryAfterMs": 2000
    }
  }
}
```

요청은 정상 접수되었지만 완료까지 시간이 필요한 작업, 재부팅 대기, deferred action,
polling 흐름에 사용한다.

---

## 4. HTTP 상태 코드 규칙

HTTP 상태 코드는 요청/전송 레벨의 결과를 나타낸다. JSON의 `code` 값은 기기 내부
또는 도메인 상태를 설명한다.

권장 매핑:

| HTTP | 의미 | 사용 예 |
|---:|---|---|
| 200 | OK | 일반적인 동기 성공 또는 상태 응답 |
| 202 | Accepted | OTA, 재부팅, deferred work처럼 요청을 받았고 나중에 완료되는 경우 |
| 400 | Bad Request | 파라미터 누락, 잘못된 JSON, 잘못된 target, 잘못된 chunk header |
| 401 | Unauthorized | API key 또는 PSK가 필요하지만 없거나 잘못된 경우 |
| 403 | Forbidden | 요청은 이해했지만 현재 기기 상태 때문에 허용되지 않는 경우 |
| 404 | Not Found | 없는 endpoint 또는 resource |
| 409 | Conflict | 세션 충돌, upload mismatch, 이미 진행 중인 작업 |
| 413 | Payload Too Large | 업로드 또는 요청 body 크기 초과 |
| 415 | Unsupported Media Type | 지원하지 않는 `Content-Type` |
| 500 | Internal Server Error | 예상하지 못한 펌웨어, 저장소, 내부 오류 |
| 503 | Service Unavailable | 재부팅 중, 네트워크 전환 중, 일시적으로 준비되지 않은 상태 |

예시:

- 업로드 세션 불일치: HTTP `409`, error code `upload_session_mismatch`
- boot guard 중 초기화 차단: HTTP `403`, error code `boot_guard_active`
- 평면도 이미지 크기 초과: HTTP `413`, error code `upload_payload_too_large`
- SPIFFS 쓰기 실패: HTTP `500`, error code `storage_write_failed`

---

## 5. 상태 및 오류 객체

`code`

- 프로그램이 읽는 안정적인 식별자다.
- 소문자 `snake_case`를 사용한다.
- 문장처럼 만들지 않는다.
- 프론트엔드 로직은 표시 문구가 아니라 이 값을 기준으로 판단한다.

`severity`

- `info`, `warning`, `error` 중 하나를 사용한다.
- UI 강조 수준, 로그, 진단 화면에 활용한다.

`detail`

- 상태 설명에 필요한 구조화 데이터다.
- 펌웨어 메모리 제약이 있으므로 작게 유지한다.
- 숫자, boolean, id, 짧은 enum 문자열을 우선 사용한다.

`message`

- 전환 기간에만 사용하는 선택 필드다.
- 로그나 임시 하위 호환용으로 사용할 수 있다.
- UI 로직은 이 값에 의존하면 안 된다.
- 새 UI 작업은 `code`에서 생성한 i18n 문구를 우선 사용한다.

---

## 6. 코드 이름 규칙

가능하면 기능 영역 prefix를 붙인다.

예시:

- `setup_wifi_connecting`
- `setup_wifi_connected`
- `setup_wifi_failed`
- `setup_ready`
- `setup_scan_started`
- `setup_scan_failed`
- `setup_ap_close_scheduled`
- `setup_ap_closing`
- `ha_handoff_started`
- `api_client_waiting`
- `api_client_connected`
- `api_client_idle`
- `calibration_ready`
- `calibration_pir_active`
- `calibration_max_zones_reached`
- `upload_started`
- `upload_committed`
- `upload_session_mismatch`
- `ota_uploading`
- `ota_reboot_waiting`
- `ota_device_reappeared`
- `debug_snapshot_ready`

code 안에 사용자 표시 문장을 넣지 않는다.

나쁜 예:

- `pir_motion_detected_cannot_start_calibration`
- `please_wait_for_home_assistant_connection`

좋은 예:

- `calibration_pir_active`
- `api_client_waiting`

---

## 7. 코드 Registry

이 registry는 일부러 작게 시작한다. 펌웨어, 대시보드, mock 모드, 문서화된 외부 동작에서
실제로 사용하는 코드만 추가한다.

### 7.1 공통 오류 코드

| Code | Severity | HTTP | 의미 | Detail |
|---|---|---:|---|---|
| `invalid_request` | error | 400 | 요청 형태 또는 파라미터가 잘못됨 | `field`, `reason` |
| `unauthorized` | error | 401 | 인증 정보가 없거나 잘못됨 | 없음 |
| `forbidden` | error | 403 | 현재 상태에서 요청이 허용되지 않음 | `reason` |
| `not_found` | error | 404 | endpoint 또는 resource가 없음 | `resource` |
| `conflict` | warning | 409 | 현재 활성 상태와 요청이 충돌함 | `reason` |
| `payload_too_large` | error | 413 | 요청 body가 허용 크기를 초과함 | `maxBytes`, `receivedBytes` |
| `unsupported_media_type` | error | 415 | 지원하지 않는 content type | `contentType` |
| `internal_error` | error | 500 | 예상하지 못한 내부 오류 | `where` |
| `service_unavailable` | warning | 503 | 기기가 일시적으로 사용 불가 | `reason`, `retryAfterMs` |

### 7.1.1 장치 설정 코드

| Code | Severity | HTTP | 의미 | Detail |
|---|---|---:|---|---|
| `config_not_found` | error | 404 | 저장된 장치 설정이 없음 | `target` |
| `config_write_failed` | error | 500 | 장치 설정을 저장하지 못함 | `target`, `where` |

### 7.2 Setup 및 Wi-Fi 코드

| Code | Severity | HTTP | 의미 | Detail |
|---|---|---:|---|---|
| `setup_wifi_connecting` | info | 200 | Wi-Fi 연결 시도 중 | `ssid` |
| `setup_wifi_connected` | info | 200 | Wi-Fi 연결 성공 | `ssid`, `ip` |
| `setup_wifi_failed` | warning | 200 | Wi-Fi 연결 실패 | `ssid`, `reason` |
| `setup_ready` | info | 200 | setup 모드가 사용자 동작을 받을 준비가 됨 | `stage` |
| `setup_scan_started` | info | 200 | Wi-Fi 스캔 시작됨 | 없음 |
| `setup_scan_failed` | error | 500 | Wi-Fi 스캔을 시작하지 못함 | 없음 |
| `setup_finish_pending` | info | 202 | setup finish 요청이 접수되어 적용 중 | 없음 |
| `setup_ap_close_scheduled` | info | 200 | 유예 시간 이후 setup AP 종료 예약됨 | `delayMs` |
| `setup_ap_closing` | info | 202 | setup AP 종료 중 | `delayMs` |
| `ha_handoff_started` | info | 200 | 사용자가 확인한 native API handoff 시작됨 | `waitSeconds` |
| `api_client_waiting` | warning | 200 | Native API client가 아직 연결되지 않음 | `uptimeSeconds` |
| `api_client_connected` | info | 200 | Native API client 연결됨 | 없음 |
| `api_client_idle` | info | 200 | Native API client 경고가 없는 대기 상태 | 없음 |
| `api_key_ready` | info | 200 | API 키가 이미 사용자 키로 준비됨 | 없음 |
| `api_key_rotated` | info | 200 | 기본/demo API 키가 교체됨 | 없음 |
| `api_key_unavailable` | error | 503 | Native API 키 서비스를 사용할 수 없음 | 없음 |
| `api_key_not_set` | error | 404 | Native API 키가 설정되어 있지 않음 | 없음 |
| `api_key_random_failed` | error | 500 | API 키 난수 생성 실패 | 없음 |
| `api_key_save_failed` | error | 500 | API 키 저장 실패 | 없음 |
| `api_key_unsupported` | error | 503 | 이 빌드에서 API 키 작업을 지원하지 않음 | 없음 |
| `wifi_unavailable` | error | 503 | Wi-Fi 서비스를 사용할 수 없음 | 없음 |
| `wifi_not_ready` | warning | 409 | Wi-Fi STA 설정이 아직 준비되지 않음 | 없음 |
| `wifi_unsupported` | error | 503 | 이 빌드에서 Wi-Fi handoff를 지원하지 않음 | 없음 |
| `open_wifi_unsupported` | error | 400 | 오픈 Wi-Fi는 지원하지 않음 | 없음 |
| `invalid_password_length` | error | 400 | Wi-Fi 비밀번호 길이가 WPA 범위를 벗어남 | `min`, `max` |
| `boot_guard_active` | warning | 403 | 초기 boot guard 중 초기화 또는 OTA 차단 | `remainingSeconds` |

### 7.2.1 시스템 관리 코드

| Code | Severity | HTTP | 의미 | Detail |
|---|---|---:|---|---|
| `nothing_selected` | warning | 400 | 초기화할 대상이 선택되지 않음 | `target` |
| `settings_reset_failed` | error | 500 | 설정 초기화 실패 | `target` |
| `stats_reset_failed` | error | 500 | 통계 초기화 실패 | `target` |

### 7.2.2 제어 API 코드

제어 API는 잘못된 요청 필드에 공통 `invalid_request` 코드를 사용한다.
마이그레이션 중에는 기존 legacy error 문자열을 유지하고, `detail`에는 잘못된
`field`와 영향을 받은 `target`을 넣는다.

| Endpoint group | Code | Severity | HTTP | Detail |
|---|---|---|---:|---|
| 제어 설정 | `invalid_request` | error | 400 | `field`, `target` |

시간대 제어는 기존의 크기가 제한된 제어 요청 패턴을 사용한다.

Endpoints:

- `GET /api/control/status`
- `POST /api/control/timezone`
- `GET /api/control/static-radar-tuning`
- `POST /api/control/static-radar-tuning/session`
- `POST /api/control/static-radar-tuning/gate`

Rules:

- `POST /api/control/timezone`은 지원하는 IANA `timezone` 식별자를 가진
  JSON object를 form field `data`로 받는다.
- 실제 시간대가 변경되면 HTTP `200`과 `changed: true`,
  `todayStatsReset: true`를 반환한다. 현재 시간대를 다시 요청해도 HTTP
  `200`을 반환하지만 `changed: false`이며 통계를 초기화하지 않는다.
  변경 적용은 비동기로 진행되며 pending 상태는 status API에서 제공한다.
- 다른 시간대를 적용할 때는 당일 카운터와 당일 히트맵만 초기화한다.
  완료된 과거 일별 기록은 유지해야 한다.
- `GET /api/control/status`는 비동기 기기 적용 완료를 확인할 수 있도록
  `timezone`, `timezoneKnown`, `timezoneApplyPending`을 제공한다.
- 지원하지 않는 시간대 식별자는 `field: timezone`, `target: timezone`을
  담은 표준 `invalid_request` envelope으로 응답한다.

LD2410C 튜닝은 평상시 거리별 계측을 실행하지 않도록 수명이 짧은
engineering 세션을 사용한다.

- `GET /api/control/static-radar-tuning`은 항상 `available`과 `active`를
  반환한다. 비활성 상태에서는 `gates`가 비어 있고, 활성 상태에서는
  G0부터 G8까지의 `startMm`, `endMm`, `sensitivity`, `moveEnergy`,
  `stillEnergy`를 반환한다. 게이트 에너지는 튜닝용 계측값이며 감지된
  타깃 위치로 해석하면 안 된다.
- `POST /api/control/static-radar-tuning/session`은 boolean `active`가
  필요하다. 활성 요청은 keepalive 역할도 하며, 15초 동안 활성
  keepalive가 없으면 펌웨어가 engineering mode를 자동으로 종료해야 한다.
- LD2410C가 없을 때 세션을 시작하면 HTTP `409`와
  `static_radar_unavailable` 코드를 반환한다.
- `POST /api/control/static-radar-tuning/gate`는 `[0, 8]` 범위의 정수
  `gate`와 `[0, 100]` 범위의 정수 `sensitivity`가 필요하다. 제품 UI의
  민감도는 `threshold = 100 - sensitivity`로 변환하여 LD2410C의 이동 및
  정지 threshold에 함께 적용한다.
- gate 변경은 engineering 세션이 활성 상태일 때만 허용한다. 그렇지
  않으면 HTTP `409`와 `static_radar_tuning_inactive` 코드를 반환한다.
- Engineering 계측은 진단 용도일 뿐이며 재실, 움직임, 타깃 좌표와 수,
  구역, 방 또는 히트맵을 변경하면 안 된다.

### 7.3 업로드 코드

| Code | Severity | HTTP | 의미 | Detail |
|---|---|---:|---|---|
| `upload_started` | info | 200 | 업로드 세션 시작 | `target`, `session`, `size` |
| `upload_committed` | info | 200 | 업로드 commit 성공 | `target`, `session`, `size`, `hash` |
| `upload_session_mismatch` | error | 409 | chunk가 활성 업로드 세션과 맞지 않음 | `expected`, `received` |
| `upload_offset_mismatch` | error | 409 | chunk offset이 예상 offset과 맞지 않음 | `expected`, `received` |
| `upload_incomplete` | error | 409 | 모든 byte를 받기 전에 commit이 요청됨 | `expected`, `received` |
| `upload_payload_too_large` | error | 413 | 업로드 payload 크기 초과 | `maxBytes`, `receivedBytes` |
| `upload_storage_failed` | error | 500 | 업로드 write 또는 commit 실패 | `target`, `where` |

### 7.3.1 기기 설정 업로드

기기 설정 저장은 floorplan 및 stats 데이터와 같은 chunked upload 패턴을 사용한다.
zone, floorplan, future multi-sensor 설정은 안전한 단일 form 요청 크기를 넘을 수 있다.

Endpoints:

- `POST /api/config/upload/start`
- `POST /api/config/upload/chunk`
- `POST /api/config/upload/commit`

Rules:

- `start`에는 `session`과 `size`가 필요하다.
- `chunk`에는 `session`, `offset`, hex-encoded `data`가 필요하다.
- `commit`에는 `session`이 필요하다.
- `commit`은 성공 응답을 반환하기 전에 저장된 device config를 firmware cache에 다시 로드해야 한다.
- `POST /api/config`, `POST /api/stats`, `POST /api/floorplan`,
  `POST /api/floorplan/image` 같은 단일 form legacy write는 embedded API에서 제거한다.
  대시보드와 복원 흐름은 chunked upload endpoint를 사용해야 한다.

### 7.3.2 평면도 부분 저장

작은 평면도 편집은 전체 평면도 문서를 다시 업로드하지 않고 전용 단일 form patch endpoint를 사용할 수 있다.
이 endpoint들은 크기가 제한된 저메모리 필드에만 사용하며, 이미지 업로드, 방 geometry 전체 교체,
wall segment 전체 교체, object 목록 전체 교체, 복원 flow에는 사용하지 않는다.

Endpoints:

- `POST /api/floorplan/radar`
- `POST /api/floorplan/room-name`
- `POST /api/floorplan/occlusion`
- `POST /api/floorplan/objects`

Rules:

- `POST /api/floorplan/radar`는 `originPx`, `rotationDeg`, `scale`을 가진 JSON object를 form field `data`로 받는다.
- `POST /api/floorplan/room-name`은 form field `id`, `name`을 받는다.
- `POST /api/floorplan/occlusion`은 `ignoredEdges`를 가진 JSON object를 form field `data`로 받는다.
- `POST /api/floorplan/objects`는 평면도 가구 object JSON array를 form field `data`로 받는다.
- 기기는 저장된 floorplan config payload의 해당 필드만 갱신하고 raw-partition metadata를 authoritative source로 유지한다.
- patch 대상이 없거나, 잘못되었거나, 너무 크면 표준 error envelope으로 `invalid_request`, `not_found`,
  또는 `upload_storage_failed`를 반환한다.
- 전체 평면도 문서 저장, 최초 저장, 복원 flow, 방 geometry 편집, scale 편집, wall segment 편집, 이미지 저장은 계속
  `POST /api/floorplan/upload/start|chunk|commit`을 사용해야 한다.

### 7.4 보정 코드

| Code | Severity | HTTP | 의미 | Detail |
|---|---|---:|---|---|
| `calibration_ready` | info | 200 | 보정 시작 가능 | 없음 |
| `calibration_started` | info | 200 | 보정 실행 시작됨 | 없음 |
| `calibration_running` | info | 200 | 보정 진행 중 | `samples`, `zone` |
| `calibration_pir_active` | warning | 409 | PIR 움직임 때문에 보정 시작 불가 | `pir` |
| `calibration_no_target` | warning | 409 | 감지된 타겟이 없어 보정 시작 불가 | 없음 |
| `calibration_multiple_targets` | warning | 409 | 타겟이 여러 개 감지되어 보정 시작 불가 | `targetCount` |
| `calibration_max_zones_reached` | warning | 409 | 더 이상 보정 구역을 만들 수 없음 | `maxZones` |
| `calibration_timeout` | error | 409 | 안정적인 보정 후보 없이 보정 종료 | `samples`, `score` |
| `calibration_candidate_failed` | error | 500 | 보정 구역 후보 생성 실패 | `samples`, `score` |
| `calibration_saved` | info | 200 | 보정 구역 저장됨 | `zone`, `count` |

### 7.5 OTA 코드

| Code | Severity | HTTP | 의미 | Detail |
|---|---|---:|---|---|
| `ota_uploading` | info | 200 | OTA 업로드 진행 중 | `bytesWritten`, `totalBytes` |
| `ota_reboot_waiting` | info | 202 | OTA 업로드 완료 후 재부팅 대기 | `retryAfterMs` |
| `ota_device_reappeared` | info | 200 | OTA 또는 재부팅 후 기기가 다시 응답함 | `version`, `buildTime` |
| `ota_verify_timeout` | warning | 503 | 제한 시간 안에 기기 응답 확인 실패 | `timeoutMs` |

### 7.6 디버그 코드

| Code | Severity | HTTP | 의미 | Detail |
|---|---|---:|---|---|
| `debug_snapshot_ready` | info | 200 | 디버그 snapshot 사용 가능 | `timestamp` |
| `debug_events_ready` | info | 200 | 진단 이벤트 로그 사용 가능 | `count`, `truncated`, `format` |
| `debug_events_empty` | info | 200 | 진단 이벤트 로그가 비어 있음 | `format` |
| `debug_events_unavailable` | warning | 503 | 진단 이벤트 로그를 일시적으로 사용할 수 없음 | `resource` |
| `debug_replay_ready` | info | 200 | 재실 리플레이 로그 사용 가능 | `count`, `truncated`, `format` |
| `debug_replay_empty` | info | 200 | 재실 리플레이 로그가 비어 있음 | `format` |
| `debug_replay_unavailable` | warning | 503 | 재실 리플레이 로그를 일시적으로 사용할 수 없음 | `resource` |

---

## 8. 프론트엔드 규칙

대시보드는 `status.code` 또는 `error.code`를 우선 사용하고, 이를 i18n 문구로
매핑한다.

예시:

```ts
const code = response.error?.code ?? response.status?.code ?? "unknown";
const text = messages.status[code] ?? messages.status.unknown;
```

Fallback 규칙:

1. `code`가 있으면 우선 사용한다.
2. `code`가 없으면 기존 legacy 필드를 사용한다.
3. 둘 다 없으면 일반적인 오류 문구를 표시한다.

프론트엔드는 한국어 또는 영어 문장을 파싱해서 동작을 판단하면 안 된다.

---

## 9. 펌웨어 규칙

펌웨어는 짧은 상태 코드와 detail을 제공한다. 임시 호환이 필요한 경우를 제외하면
API 응답에 사용자 표시용 문장을 계속 추가하지 않는다.

일반 API에 큰 진단 payload를 넣지 않는다. 자세한 진단 정보가 필요하면 별도의
debug endpoint를 사용한다.

많은 record를 반환할 수 있는 debug endpoint는 firmware memory 안에서 하나의 큰
문자열을 만들지 말고 streaming 또는 chunk 응답으로 내보낸다.

리플레이 진단 정보는 전용 debug endpoint를 통해 newline-delimited sample로
제공할 수 있다. 리플레이 payload는 오프라인 테스트용이며 일반 status 응답에
넣지 않는다.

리플레이 진단에는 시간이 지나면서 작은 선택 tuple이 추가될 수 있다. 소비자는 알 수 없는
필드를 무시해야 하며, 선택 필드가 없을 때는 안전한 기본값을 사용해야 한다.
예를 들어 `ex` tuple은 exit zone 근거를
`[exitActive, exitZoneMask, exitTargetCount, exitLastSeenAgeMs]` 형태로 보고한다.

---

## 10. 호환성 정책

기존 필드는 즉시 제거하지 않는다.

마이그레이션은 다음 순서를 따른다.

1. 기존 응답 옆에 `code`, `severity`, `detail`을 추가한다.
2. mock/demo API도 같은 필드를 반환하게 한다.
3. 프론트엔드는 code 기반 문구를 우선 사용하게 바꾼다.
4. 새 경로가 안정화될 때까지 legacy 필드를 유지한다.
5. 대시보드와 펌웨어 검증 후 legacy 의존을 제거한다.

---

## 11. 전환 우선순위

권장 순서:

1. 진단 및 디버그 API
2. 보정 상태
3. 평면도 업로드 상태 및 오류
4. setup 및 Wi-Fi handoff 상태
5. OTA 업로드 및 재응답 확인 상태
6. `/api/system/status`

이유:

- 디버그와 보정은 비교적 독립적이라 먼저 적용하기 쉽다.
- 업로드, setup, OTA 흐름은 민감하므로 패턴 검증 후 바꾼다.
- `/api/system/status`는 여러 곳에서 쓰이므로 신중하게 바꾼다.

---

## 12. 설정 Enum

Software zone type:

| 값 | 의미 |
| --- | --- |
| `detection` | 구역 안의 target을 zone presence로 계산한다. |
| `filter` | 구역 안의 target을 오탐 후보로 보고 차단한다. |
| `disabled` | 구역을 설정에는 보존하지만 감지에는 사용하지 않는다. |
| `exit` | 사람이 감지 영역을 나가는 경로 후보를 표시한다. 이것은 exit evidence이며 filter가 아니다. |

Calibration zone type:

| 값 | 의미 |
| --- | --- |
| `filter` | 반복되는 오탐 후보를 차단한다. |
| `reduced` | 반복 후보를 바로 막지 않고 일정 시간 지연 후 통과시킨다. |
| `disabled` | 보정 구역을 설정에는 보존하지만 사용하지 않는다. |

`exit`은 software zone type 전용이다. calibration zone type으로 취급하면 안 되며
그 자체로 target을 제거하면 안 된다.

---

## 13. 금지 사항

하지 말 것:

- 기존 API 응답을 한 번에 크게 깨지 말 것.
- 표시 문자열에 의존하는 프론트 로직을 새로 만들지 말 것.
- 펌웨어 API 문구를 직접 번역해서 내려주지 말 것.
- 긴 문장을 status code처럼 쓰지 말 것.
- 일반 status 응답에 큰 로그를 넣지 말 것.
- 다국어 작업 중 endpoint 의미를 같이 바꾸지 말 것.
- peer 기기끼리 사용자 표시 문장을 주고받게 만들지 말 것.
- 명시적인 geometry 설정 없이 여러 센서의 좌표를 합치지 말 것.
- exit zone을 filter zone처럼 사용하지 말 것.

---

## 14. 이 프로젝트의 실무 규칙

당분간 새 상태 응답을 만드는 작업은 아래 규칙을 따른다.

```json
{
  "ok": true,
  "status": {
    "code": "feature_state",
    "severity": "info",
    "detail": {}
  }
}
```

기존 문자열 필드는 남겨도 되지만, 새 UI 작업은 `code`를 우선 사용한다.

---

## 15. LD2410C 재실 보조 규약

`GET /api/state`의 `debug.staticRadar`는 LD2410C 입력과 재실 보조 상태를 제공한다.
`detectionDistanceMm`은 LD2410C가 보고한 단일 최종 감지 거리에 최근
3개 중앙값 필터를 적용한 값이다. 1초에 최대 한 개의 거리만 중앙값 이력에
넣으며, 짧은 유효하지 않은 거리값은 마지막 안정값을 덮어쓰지 않는다.
보조 레이더 재실이 해제되거나 센서가 없어지면 필터 상태를 초기화한다.
`movingDistanceMm`과 `stillDistanceMm`은 진단용 원시값이며 클라이언트가
두 값을 조합해 타깃 위치를 추론하면 안 된다.
`assist` 객체는 `armed`, `active`, `armPending`, `armElapsedMs`, `exitVeto`와 선택적인
`heldTarget` 스냅샷을 포함한다.
LD2410C 타깃 위치를 표시하는 클라이언트는 `presence`와 단일
`detectionDistanceMm`만 사용해야 한다.
`debug.presenceEvidence`는 PIR, LD2450 트래커, LD2410C 보조 증거를 각각 표시한다.

LD2410C는 PIR 또는 확정된 LD2450 트랙으로 이미 시작된 재실 세션만 유지할 수 있다.
LD2410C 단독으로 재실을 새로 켜면 안 되며 움직임, 활성 타깃 좌표와 개수, 방 상태,
구역 재실 또는 히트맵 샘플을 만들면 안 된다.
현재 drop 이벤트가 `lost_after_exit` 또는 `lost_after_room_exit`이면 해당 소실에 대해 새로운 정적 레이더 hold를 시작하지 않는다.
LD2410C가 없거나 통신할 수 없으면 `available: false`로 처리하고 기존 PIR 및 LD2450 동작을 그대로 유지한다.

보조 유지가 활성화된 동안 `assist.heldTarget`은 정확히 하나였던 마지막 확정 또는 코스팅
LD2450 트랙의 좌표를 표시 목적으로만 보존할 수 있다. 명확한 이전 공간 타깃이 없으면
`null`이다. 이 스냅샷은 활성 타깃이 아니며 타깃 수, 구역, 방, 보정 또는 히트맵 계산에
포함하면 안 된다.

```json
{
  "heldTarget": {
    "id": "target_1",
    "x": 600,
    "y": 1800,
    "lastDistanceMm": 1897,
    "staticDistanceMm": 1950,
    "distanceDeltaMm": 53,
    "distanceMatched": true
  }
}
```

안정화된 `detectionDistanceMm`을 사용할 수 없거나 값이 유효하지 않으면
`staticDistanceMm`과 `distanceDeltaMm`은 `null`이고 `distanceMatched`는 `false`다. 대시보드는 거리 일치
스냅샷을 기존 타깃 모습으로, 불일치 스냅샷을 위치 불확실 상태로 표시할 수 있다.

리플레이의 선택적 `sr` 튜플은 다음 순서로 정적 레이더 근거를 기록한다.

```text
[available, presence, moving, still, movingDistanceMm, stillDistanceMm, movingEnergy, stillEnergy, detectionDistanceMm]
```

리더는 기존 8개짜리 튜플도 받아야 하며 빠진 `detectionDistanceMm`은 `0`으로
처리한다.

리플레이의 선택적 `sf` 튜플은 다음 순서로 융합 상태를 기록한다.

```text
[pirEvidence, trackerEvidence, assistArmed, assistActive, armPending, exitVeto, armElapsedMs]
```

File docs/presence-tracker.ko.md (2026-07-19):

# 재실 트래커와 센서 융합

이 문서는 필터링된 LD2450 관측값에서 최종 재실·움직임 출력까지 이어지는 현재
production 경로를 설명한다.

## 1. 런타임 경로

- 트래커 경로가 기본값이다. 기존 lambda 경로는 고급 설정의 legacy 재실 옵션을
  통한 명시적인 fallback으로 남아 있다.
- 500ms ESPHome lambda는 필터링된 LD2450 관측값, PIR 상태, 방/퇴실 근거와
  선택적인 LD2410C 근거를 C++ 컴포넌트로 전달한다.
- `PresenceTracker`는 LD2450 track identity, 생명주기, 위치, 속도, 방향, 방 경계
  통과와 퇴실 근거를 소유한다.
- `PresenceFusion`은 PIR과 트래커 근거를 결합하고, 선택적인 LD2410C는 PIR 또는
  확정된 LD2450 트랙이 이미 시작한 세션을 유지할 때만 사용한다.
- 출력은 `/api/state`, Home Assistant 엔티티, 진단 및 리플레이 로그에 노출된다.

## 2. LD2450 추적

트래커는 LD2450 하드웨어 한도에 맞춰 관측값과 유지 중인 트랙을 각각 최대 3개
처리한다. 일반적인 Hungarian 구현 대신 가능한 작은 assignment 조합을 직접
평가한다.

트랙 상태는 다음과 같다.

- `tentative`: 최근 관측 횟수가 충분해질 때까지 대기한다.
- `confirmed`: 재실과 움직임/정지 개수에 직접 반영된다.
- `coasting`: 관측이 사라진 뒤 제한된 시간 동안 유지된다.
- `idle`: 사용하지 않는 슬롯이다.

위치와 속도는 시간 간격, process noise, measurement noise와 covariance를 제한한
등속도 Kalman filter를 사용한다. 순간 이동에 가까운 큰 관측 변화는 이전 추정치를
억지로 끌고 가지 않고 필터를 초기화한다. confirmed/coasting 트랙은 새 tentative
트랙보다 넓은 재연결 범위를 사용한다.

`trackScore`는 최근 hit, miss와 생명주기 상태에서 계산한 진단 점수다. 확률이나
사용자용 신뢰도 퍼센트가 아니다.

## 3. 퇴실 및 방 근거

각 트랙은 최근 퇴실 지점 진입과 방 경계 상태를 기록한다.

- 최근 설정된 퇴실 지점을 지난 트랙은 coasting이 짧아지고
  `lost_after_exit`으로 종료될 수 있다.
- 신뢰할 수 있는 방 안쪽에서 바깥쪽으로의 경계 통과는
  `lost_after_room_exit`이 될 수 있다.
- 두 근거 없이 사라지면 `lost_without_exit`이 되고 더 긴 비퇴실 coasting 정책을
  사용한다.
- `filter_blocked`는 관측 miss 한 프레임으로 처리하며 모든 트랙을 즉시
  초기화하지 않는다.

현재 drop 이벤트는 `PresenceFusion`이 소비한다. 확인된 퇴실 drop은 해당 소실에
대한 새로운 LD2410C hold를 막는다.

## 4. 재실 융합

PIR과 LD2450은 서로 보완하는 재실 획득 근거다. PIR 움직임 또는 confirmed/coasting
트래커 결과가 base presence를 유지할 수 있다. 필터가 막지 않는 한 움직임은 PIR
움직임과 트래커 움직임의 OR이다.

LD2410C 보조 규칙은 다음과 같다.

- 하드웨어가 없으면 `available: false`로 조용히 무시한다.
- LD2410C 단독으로 재실, 움직임, 타깃 개수, 방·구역 상태 또는 히트맵을 만들지
  않는다.
- 기존 PIR/트래커 세션과 정적 레이더 재실이 2초 동안 겹쳐야 보조가 armed된다.
- 확인된 퇴실 근거 없이 LD2450이 사라지면 armed된 LD2410C가 재실을 유지할 수
  있다.
- 퇴실/filter veto 없이 안정화 재실이 끝나면 이미 armed된 보조에 한해 30초 동안
  같은 세션의 재진입 기회를 한 번 허용한다.
- PIR 또는 LD2450이 다시 감지되면 primary/secondary 전환 없이 원래의 결합 근거로
  돌아간다.

표시 목적으로만, 보조가 명확한 단일 confirmed/coasting LD2450 트랙의 마지막
좌표를 유지할 수 있다. 이 좌표는 활성 타깃이 아니며 타깃 개수, 방, 구역, 보정,
히트맵 계산에서 제외한다.

## 5. 정적 레이더 거리 안정화

held-target 표시 신뢰도에는 LD2410C의 `detectionDistanceMm`만 사용한다.

- 1초에 최대 한 개의 유효 거리만 최근 3개 중앙값 이력에 넣는다.
- 첫 유효 샘플은 즉시 표시한다.
- 한 번의 튐은 안정값을 바꾸지 못한다.
- 정적 재실이 유지되는 동안 짧은 유효하지 않은 거리값은 마지막 안정값을
  유지한다.
- 정적 재실이 해제되거나 센서가 사용 불가가 되면 거리 이력을 초기화한다.
- 이동/정지 거리와 energy는 원시 진단값이며 위치 추론에 조합하지 않는다.

## 6. 검증과 한계

- 네이티브 테스트는 생명주기, assignment, Kalman smoothing, 퇴실/방 drop, 융합
  arming, exit veto, 재진입, 하드웨어 없음, held-target 신뢰도와 거리 안정화를
  다룬다.
- 리플레이 로그는 raw 관측, production 필터 관측, 트래커 출력, 퇴실 근거,
  정적 레이더 입력과 융합 상태를 구분한다.
- BLE nearby와 수면 시간 설정은 재실 획득 근거가 아니다.
- 트랙 정책 상수와 LD2410C 거리 일치는 다양한 실제 설치 환경에서 계속 검증해야
  한다.

향후 실험은 [presence-tracker-future.ko.md](presence-tracker-future.ko.md)에 둔다.

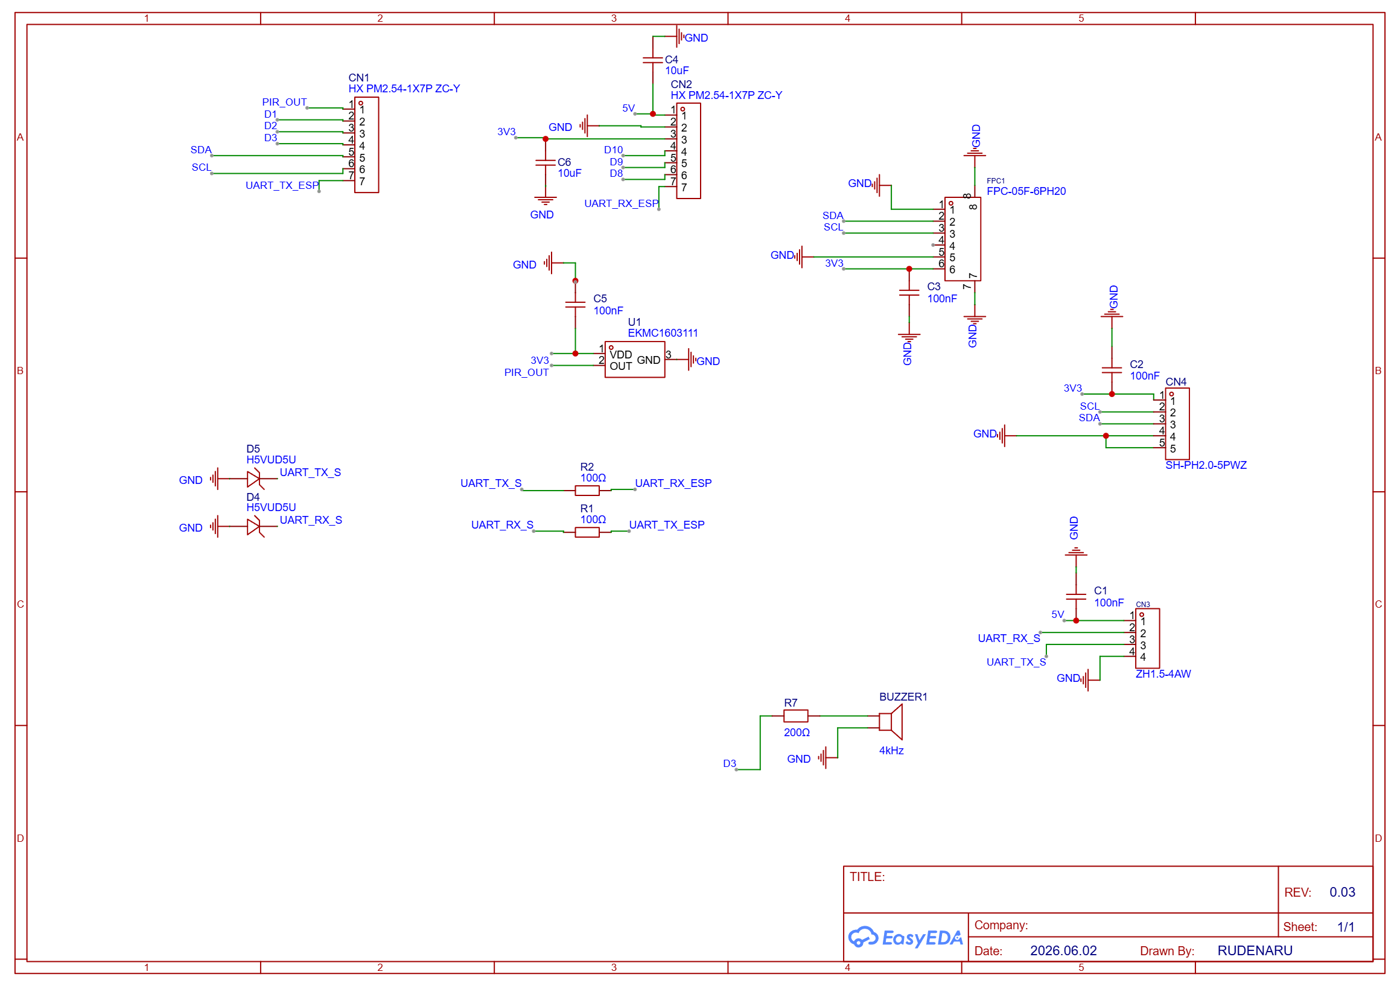
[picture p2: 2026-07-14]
hardware/pcb/single_sensor/schematic.png

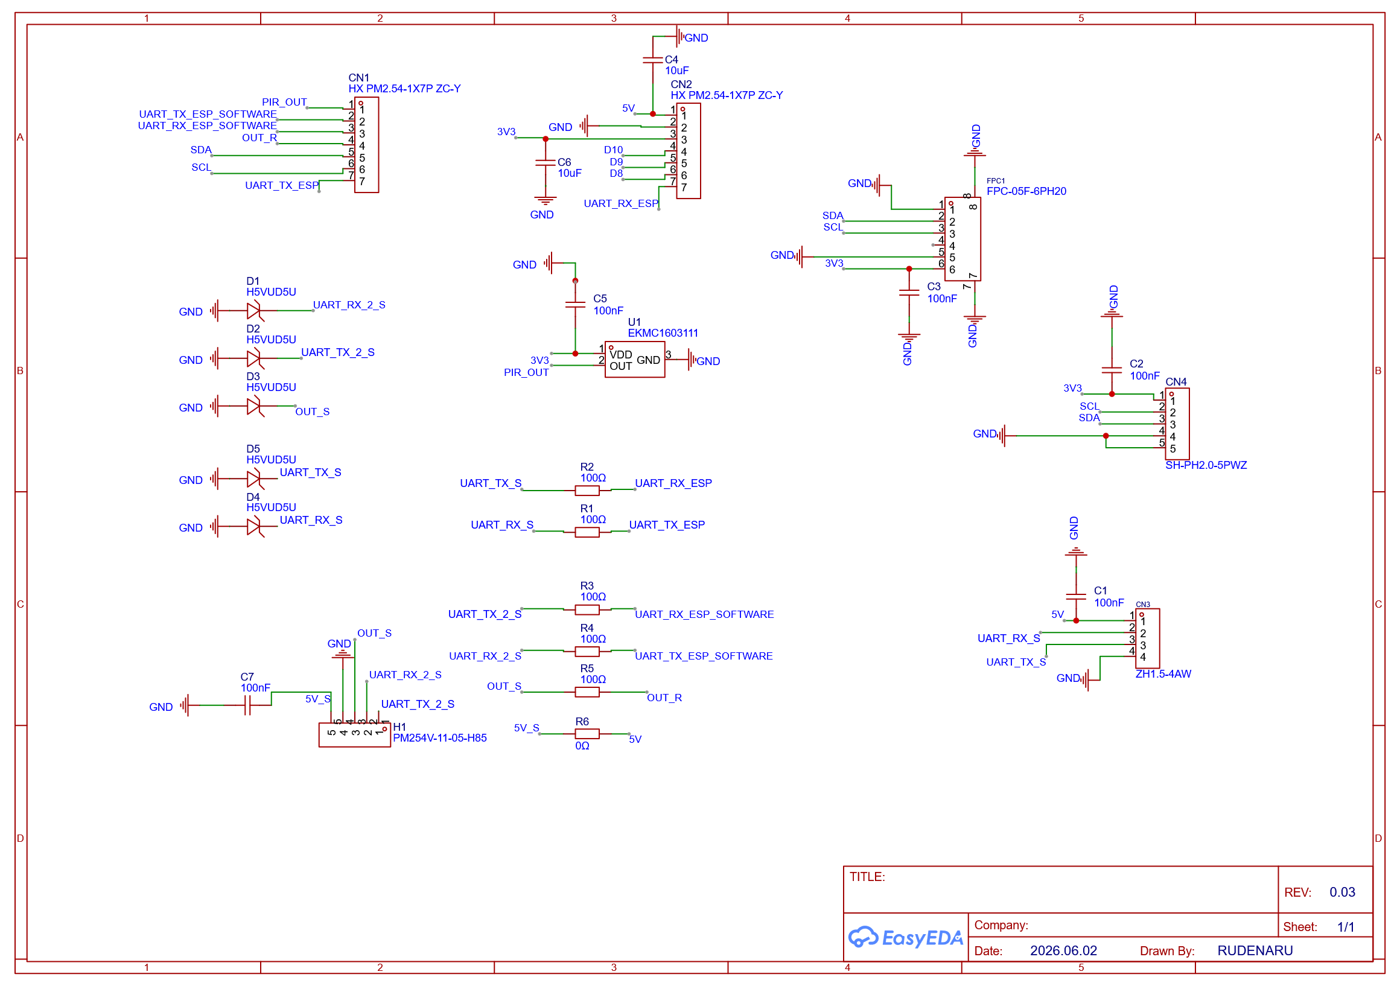
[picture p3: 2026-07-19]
hardware/pcb/dual_sensor/schematic.png

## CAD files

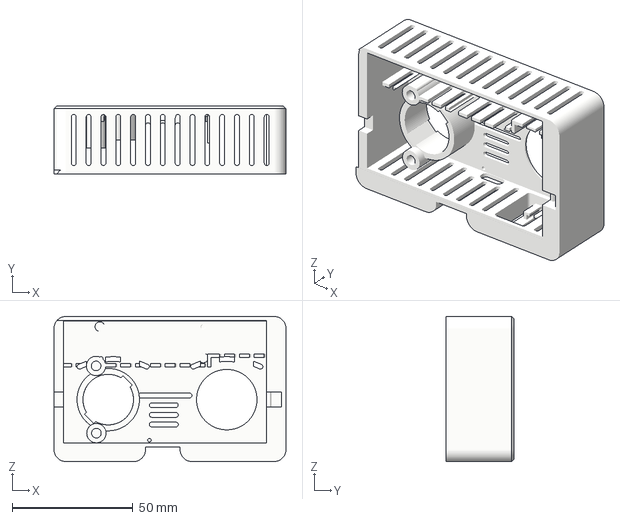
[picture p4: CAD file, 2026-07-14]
hardware/enclosure/top.3mf
96.0 x 28.0 x 60.1 mm

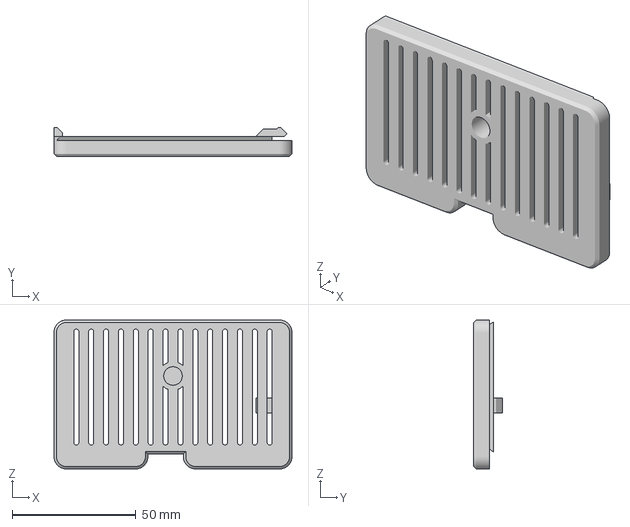
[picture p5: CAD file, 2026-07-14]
hardware/enclosure/bottom.3mf
96.0 x 11.6 x 60.1 mm

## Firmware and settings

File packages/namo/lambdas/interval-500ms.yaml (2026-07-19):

|-
  const uint32_t now = millis();
  
  // === 섹션 1: 존/보정 설정 파싱 및 point-in-polygon 헬퍼 ===
  // radar_api에 저장된 software/calibration zone JSON을 읽고, 타입 판정과 점 포함 여부를 계산한다.
  // 설정이 없거나 깨진 경우 각 헬퍼가 false/0을 반환하도록 설계되어 있으며, 조기 반환으로 전체 감지를 중단하지 않는다.
  // 직접 만든 문자열 파서는 임베디드 힙 사용을 낮추기 위한 경량 경로이므로 동작 보존이 중요하다.
  auto clamp_value = [](float value, float min_value, float max_value) -> float {
    if (value < min_value) return min_value;
    if (value > max_value) return max_value;
    return value;
  };
  
  auto zone_config_for = [&](int zone_index) -> std::string {
    const std::string cached = id(radar_api).software_zone_config(zone_index);
    if (!cached.empty()) return cached;
    return "";
  };
  
  auto calibration_config_for = [&](int zone_index) -> std::string {
    const std::string cached = id(radar_api).calibration_zone_config(zone_index);
    if (!cached.empty()) return cached;
    return "";
  };
  
  auto zone_config_valid = [&](const std::string &value, int zone_index) -> bool {
    std::string needle = std::string("\"id\":\"zone_") + std::to_string(zone_index) + "\"";
    return !value.empty() && value != "__EMPTY__" && value.find(needle) != std::string::npos && value.find("\"points\"") != std::string::npos;
  };
  
  auto calibration_config_valid = [&](const std::string &value, int zone_index) -> bool {
    std::string needle = std::string("\"id\":\"calibration_") + std::to_string(zone_index) + "\"";
    return !value.empty() && value != "__EMPTY__" && value.find(needle) != std::string::npos && value.find("\"points\"") != std::string::npos;
  };
  
  auto zone_type_is = [&](int zone_index, const char *type) -> bool {
    const std::string zone_config = zone_config_for(zone_index);
    if (!zone_config_valid(zone_config, zone_index)) return false;
    std::string needle = std::string("\"type\":\"") + type + "\"";
    return zone_config.find(needle) != std::string::npos;
  };
  
  auto point_in_zone_config = [&](const std::string &zone_config, float tx, float ty) -> bool {
    const size_t end = zone_config.size();
    size_t points_pos = zone_config.find("\"points\"");
    if (points_pos == std::string::npos || points_pos >= end) return false;
  
    float xs[8];
    float ys[8];
    int point_count = 0;
    size_t pos = zone_config.find('[', points_pos);
    if (pos == std::string::npos || pos >= end) return false;
  
    auto read_number = [&](size_t &cursor, float &value) -> bool {
      while (cursor < end && !(zone_config[cursor] == '-' || (zone_config[cursor] >= '0' && zone_config[cursor] <= '9'))) cursor++;
      if (cursor >= end) return false;
      const size_t number_start = cursor;
      if (zone_config[cursor] == '-') cursor++;
      while (cursor < end && zone_config[cursor] >= '0' && zone_config[cursor] <= '9') cursor++;
      value = atof(zone_config.substr(number_start, cursor - number_start).c_str());
      return true;
    };
  
    while (pos < end && point_count < 8) {
      float x = 0;
      float y = 0;
      if (!read_number(pos, x)) break;
      if (!read_number(pos, y)) break;
      xs[point_count] = clamp_value(x, -4860.0f, 4860.0f);
      ys[point_count] = clamp_value(y, 0.0f, 7560.0f);
      point_count++;
      size_t next = zone_config.find('[', pos);
      size_t zone_close = zone_config.find("]]", pos);
      if (next == std::string::npos || (zone_close != std::string::npos && zone_close < next) || next >= end) break;
      pos = next;
    }
  
    if (point_count < 3) return false;
    bool inside = false;
    for (int i = 0, j = point_count - 1; i < point_count; j = i++) {
      const bool intersects = ((ys[i] > ty) != (ys[j] > ty)) &&
        (tx < (xs[j] - xs[i]) * (ty - ys[i]) / ((ys[j] - ys[i]) == 0 ? 0.0001f : (ys[j] - ys[i])) + xs[i]);
      if (intersects) inside = !inside;
    }
    return inside;
  };
  
  auto point_in_software_zone = [&](int zone_index, float tx, float ty) -> bool {
    const std::string zone_config = zone_config_for(zone_index);
    if (!zone_config_valid(zone_config, zone_index)) return false;
    return point_in_zone_config(zone_config, tx, ty);
  };
  
  auto calibration_zone_type_is = [&](int zone_index, const char *type) -> bool {
    const std::string zone_config = calibration_config_for(zone_index);
    if (!calibration_config_valid(zone_config, zone_index)) return false;
    std::string needle = std::string("\"type\":\"") + type + "\"";
    return zone_config.find(needle) != std::string::npos;
  };
  
  auto point_in_calibration_zone_type = [&](int zone_index, const char *type, float tx, float ty) -> bool {
    const std::string zone_config = calibration_config_for(zone_index);
    if (!calibration_config_valid(zone_config, zone_index)) return false;
    if (!calibration_zone_type_is(zone_index, type)) return false;
    return point_in_zone_config(zone_config, tx, ty);
  };
  
  auto point_in_any_calibration_zone_type = [&](const char *type, float tx, float ty) -> bool {
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

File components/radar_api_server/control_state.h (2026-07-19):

#pragma once

#include <array>
#include <cstdint>
#include <string>

namespace esphome {
namespace radar_api_server {

struct StaticRadarGateTuningState {
  float move_energy{0.0f};
  float still_energy{0.0f};
  float move_threshold{100.0f};
  float still_threshold{100.0f};
};

struct ControlState {
  static constexpr size_t STATIC_RADAR_GATE_COUNT = 9;

  bool status_led_enabled = true;
  bool has_status_led_enabled = false;
  float led_blink_duration = 60.0f;
  bool has_led_blink_duration = false;
  bool environment_correction_enabled = true;
  bool has_environment_correction_enabled = false;
  float temperature_offset = 0.0f;
  bool has_temperature_offset = false;
  float humidity_offset = 0.0f;
  bool has_humidity_offset = false;
  std::string timezone{"Asia/Seoul"};
  bool has_timezone = false;

  bool pending_status_led_enabled = false;
  bool requested_status_led_enabled = true;
  bool pending_led_blink_duration = false;
  float requested_led_blink_duration = 60.0f;
  bool pending_environment_correction_enabled = false;
  bool requested_environment_correction_enabled = true;
  bool pending_temperature_offset = false;
  float requested_temperature_offset = 0.0f;
  bool pending_humidity_offset = false;
  float requested_humidity_offset = 0.0f;
  bool pending_timezone = false;
  std::string requested_timezone{"Asia/Seoul"};

  bool static_radar_available = false;
  bool static_radar_tuning_active = false;
  bool static_radar_tuning_requested_active = false;
  bool pending_static_radar_tuning_session = false;
  uint32_t static_radar_tuning_keepalive_ms = 0;
  uint16_t static_radar_gate_resolution_mm = 750;
  std::array<StaticRadarGateTuningState, STATIC_RADAR_GATE_COUNT> static_radar_gates{};
  bool pending_static_radar_gate = false;
  uint8_t requested_static_radar_gate = 0;
  uint8_t requested_static_radar_sensitivity = 0;
};

}  // namespace radar_api_server
}  // namespace esphome

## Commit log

2026-07-14 refine readme
    [bottom.3mf, top.3mf]
2026-07-19 feature update
    - Add LD2410C sub sensor support
    - Add sensitivity tuning for LD2410C
    - Add new logic for presence detection
    [partitions-8mb.csv]
2026-07-19 update PCB
2026-08-21 Update dual radar sensor enclosure file
2026-08-21 update case file for LD2454
2026-08-21 V0.6.0 minor update
    Added secure pairing, calibration, and target fusion for up to seven NAMO devices.
    Improved automatic Owner, Site Leader, and Group Leader election and failover.
    Added manual floorplan drawing with physical walls, rooms, doors, and radar occlusion.
    Added signed Release OTA, Legacy OTA for older firmware, and Factory images.
    Added one-time alpha firmware installation approval and update completion dialogs.
    Improved pairing, calibration, device removal, automatic replacement, and mock workflows.
    Expanded Home Assistant integration and user/developer documentation.
    Updated vulnerable development dependencies, including PostCSS.
    Strengthened release builds, exports, versionin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
2026-08-26 (Hotfix) Fix bug while connecting completely new device
    - Fixed intermittent site_directory_not_ready errors when pairing or calibrating factory-reset devices.
    - Added bounded retries when Floorplan replication temporarily returns busy, instead of immediately aborting pairing.
    - Allowed quarantined devices to catch up from the Configuration Owner only when it provides a strictly newer canonical Site Directory. Equal-revision conflicts remain fail-closed.
    - Fixed heartbeat compatibility probes becoming phase-locked when expanding beyond five devices.
    - Fixed 5→6→7 device expansion being treated like a fresh Group election.
    - Preserved the existing eligible Group Leader while the canonical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
